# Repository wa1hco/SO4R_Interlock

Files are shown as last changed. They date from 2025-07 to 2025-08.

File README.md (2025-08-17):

# SO4R_Interlock V2
The interlock manages up to 4 radios for a contesting scenario

Baseline capability for one SSB/CW radio plus 3 WSJTX radios.
Antenna separation is sufficient to allow reception when other radio is transmitting
SSB/CW radio has an amplifier and rotatable antenna

Each of three WSJTx instances have radio and antenna (generally fixed).  Amplifier is shared among radios
WSJTX feeds N1MM, Gridtracker or other program that display a combined list of stations needed.
Operator clicks on a station in the list and that WSJTX begins the contact.
SSB/CW operator can continue to operate, which interrupts WSJTX transmission.

Each of 4 radio have a priority with SSB/CW being highest
SSB/CW operation can continue while WSJTX is making contacts while staying within the ARRL VHF contest rules

When a higher priority tranmitter needs to interrupt a lower priority tranmission, 
the interlock gates the PTT line to the lower priority radio.  This keeps the radio's
built in sequencer operating to protect the amplifier, preamp, and relays.  
The interlock also controls the RF relays to disconnect the lower priority transmitter 
and connect the highest priority transmitter

Radio Interface
* PTT, output open collector, low true, 60V, 300 mA
* KEY, input, open collector, low true, 5 to 15 V
* CAT, bidirectional, open collector, ttl levels, serial communication
* Spare, direct connection to MCU I/O pin

Relay interface
* Relay output are drive high from nominal 12V source
  * uses BTS5200-4 driver chip for fault protection and diagnositc capability
* 12V is sourced from a rig interface for from coaxial type M connector
* each output drives DPDT transfer relay and one port of 4:1 selector on both amp input and output

USB serial interface
* Implemented with FTDI FT230 usb serial chip
* TxD, RxD, for CAT
* RTS, output, for signaling Transmit
* CTS, input, available, interfaced to MCU, no function assigned
* USB EEPROM changed to make it easier to find the ports
  * Manufacturer is "FTDI WA1HCO"
  * Product is "FT230X SO4R Port {1-4}"

SSB/CW radio interface
* highest priority radio, Priority = 1
* USB serial TxD, RxD used for MCU programming
* USB serial RTS used for keying radio from N1MM
* KEY signal from Radio used to set priority and control relays

WSJTX radio interface
* Lower priority radios, Priority = 2, 3, or 4
* USB serial implements COM port used by WSJTX software
* Serial data TxD and RxD converted to CAT bidirectional open collector
* RTS signal used for Tx command to radio
* CTS signal routed to MCU but not assigned a function

WSJTX operation
* Operator uses ssb/cw radio for contacts and has highest priority for transmitting.
* 3 WSJTX instances listen on 3 radios in 3 directions.
* Each WSJTX sends it list of callsigns to N1MM or Gridtracker which displays list of needed stations.
* The operator clicks on a callsign in the list to start a WSJTX contact.
* WSJTX indicates need to transmit by asserting RTS on its serial interface

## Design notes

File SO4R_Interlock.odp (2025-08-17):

## SO4R Interlock System Engineering: Fred Lass, K2TR Design: Jeff Millar, WA1HCO

## Baseline SO4R Interlock System Diagram

FT8 PC

WSJT

Main rig interfaces

CAT, Tx Audio, Rx Audio

Transfer Relays

radio

Ant 4

FT8 PC

WSJT

RTS

CAT, Tx Audio, Rx Audio

PTT

radio

Ant 3

FT8 PC

WSJT

CAT, Tx Audio, Rx Audio

CAT, Tx Audio, Rx Audio, PTT, CW

SO4R

Interlock

Connectors USB-C, DC type M, RJ45

radio

Ant 2

SSB PC

N1MM

RTS

PTT

radio

Ant 1

WSJTX to rig interface

- CAT, Audio via rig USB

- Interlock USB used for RTS

Interlock determines priority

- Based on RTS or KEY inputs

- Highest priority gets PTT

SSB/CW rig sends KEY to Interlock

RTS flows to PTT if highest priority

RTS

USB

4

radio

4

4

PTT

4:1 Mux Relays

3

2

3

3

2

2

KEY

12V, if not from

rig interface

1

12V

1

1

RLY

Relay Control

radio 1, Mux 1

radio 2, Mux 2

radio 3, Mux 3

radio 4, Mux 4

Amp

Transfer relays connect

- Rig to antenna for Rx

- Rig to Amp to Antenna for Tx

Mux relays route priority rig thru amp

## SO4R Interlock Principles of Operation

- Interlock for four radios, ensures only one Tx at a time
  - Read RTS signals from WSJTX
  - Read KEY signal from SSB/CW Rig
  - Determine Priority from RTS and KEY inputs
  - Assert PTT to the highest priority WSJT rig if no SSB/CW key
  - Repeat every 20 to 50 usec
- SSB/CW radio has highest priority
  - Tx is controlled by VOX, Footswitch, CW key, not by Interlock
  - KEY from SSB/CW rig signal tells Interlock to block PTT to other rigs
- Interlock forwards WSJTX RTS signal to rig PTT

## SO4R Interlock Hardware Design

- FT230X USB serial interface
  - RTS to microcontroller
- Rig Interface, RJ45, 4 twisted pair of signal and ground
  - PTT output, open collector, 60V, 300 mA
  - KEY input, open collector, external pullup, protected to 15V
  - CAT in/out, open collector, 5V (growth option)
  - 12V, input from Rig, replaces ground on CAT pair
  - Spare (growth option)
- Relay Interface, RJ45, 4 twisted pair, relay and ground
  - Drive 12V to external relays,
  - Relay driver is BTS4200-4 with protection and diagnostics
  - Typically three Omron G2RL-1-E-12V with 80 mA draw per relay
- 12V, DC power for relays, need 240 mA
  - Used if Rig power not available
- AVR32DB48 microcontroller
  - Programmed using port 1 USB serial
  - Green LED for 5V power
  - White LEDs for serial traffic
- Electrical design
  - EMI filtering on all I/O
  - ESD protection on all inputs
  - 4 layer PCB
  - Three flooded ground planes
  - One flooded 5V plane
  - Interlock powered from any USB
  - Relays powered from any rig or 12V coaxial

## Interlock Schematic Diagram

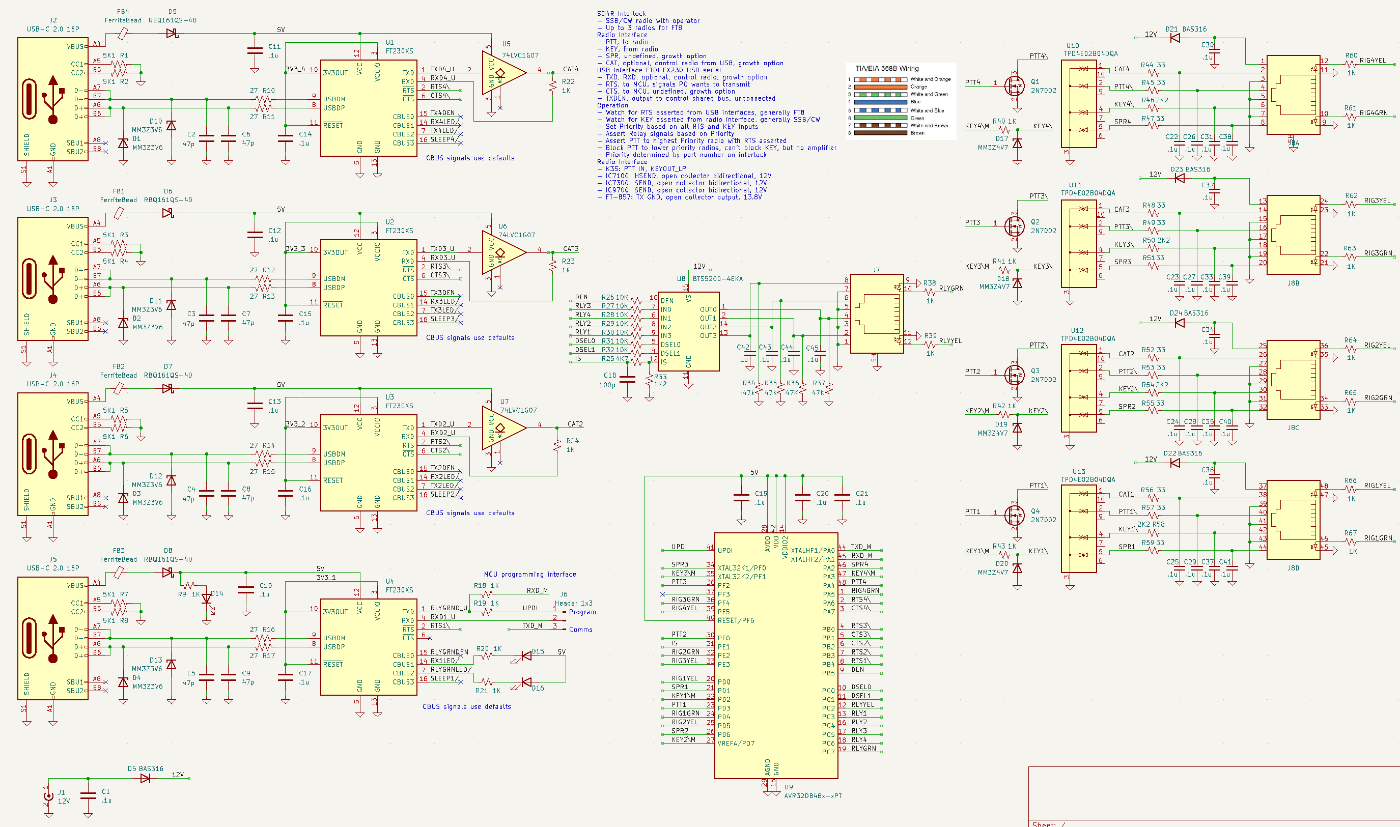
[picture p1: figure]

## SO4R Interlock Functional Design

- MicroController
  - Reads RTS and KEY inputs
  - Writes PTT, Relay, and indicator LED outputs
- Combinatorial logic with latency below 100 usec
- Relay protection relies on Rig Tx delay
- Rig timing assumptions
  - PTT asserted to rig causes KEY output from rig immediately (usec)
  - PTT asserted to RF output delayed by 15 msec or more
  - PTT release causes RF to stop in about 300 usec (filter delays)
  - PTT release causes KEY output to be released immediately (usec)
- Conclusion, no need for sequencing within Interlock

## Corner Cases

- Operator presses TX button on WSJT radio
  - LP radio _will_ go into transmit
  - Radio asserts KEY output
  - Interlock reads KEY and lights yellow LED on rig RJ45
  - Interlock does not assert relays, Tx power flows to antenna not amplifier
- If SSB/CW radio already transmitting
  - Relays set to SSB/CW radio uses amplifier
  - WSJT rig transfer relays remain in rig to antenna mode
  - LP Tx power flows to antenna
  - LP RJ45 shows Yellow LED on Interlock
- If HP radio starts Tx while LP Radio in Tx
  - Interlock sees KEY from HP radio
  - Interlock asserts relays for HP radio
  - LP radio RJ45 remains yellow
  - HP radio RJ45 shows green

## SO4R Interlock LEDs

- Each RJ45 connector has a green and a yellow LED
- Rig interface
  - Green LED means radio is transmitting
    - RTS asserted, highest priority, PTT asserted, Relays asserted
  - Yellow LED means radio wants to transmit but blocked
    - RTS asserted, not highest priority, PTT blocked by Interlock
    - KEY asserted because operator pressed Transmit on radio

## Interlock to Rig Interface Cables

- Make Cable
  - Use CAT 5/6 Ethernet cable
  - Cut in half to make two cables with RJ45
  - Expose 4 twisted pairs, strip ends
  - Solder on rig interface connectors
  - Strain Relief the junction
- Sample schematic on the right
  - Not based on experience with K3
  - Use KEY/, PTT/, and GND on DE15
  - Show ¼ inch phone jack and plug for PTT (optional)
  - Pick up 13.8V (optional)

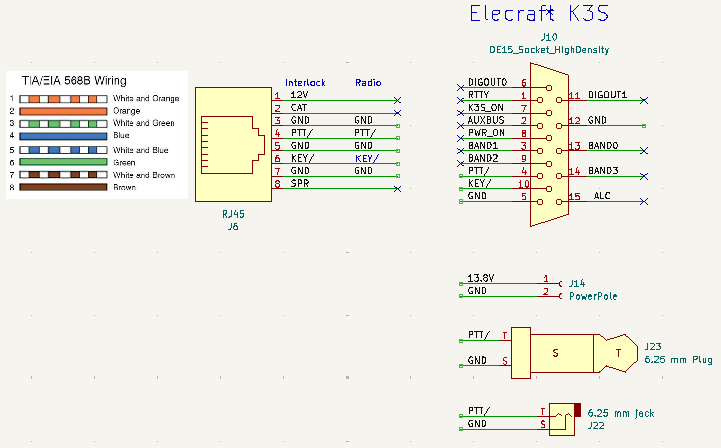
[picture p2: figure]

## WSJTX USB Interface from PC

- Separate USB interfaces
  - Linux WSJTX example shown
  - CAT Control USB
    - /dev/ttyUSB0
  - PTT Method USB set to RTS
    - /dev/ttyUSB1
- On Windows use separate COM ports for CAT and RTS

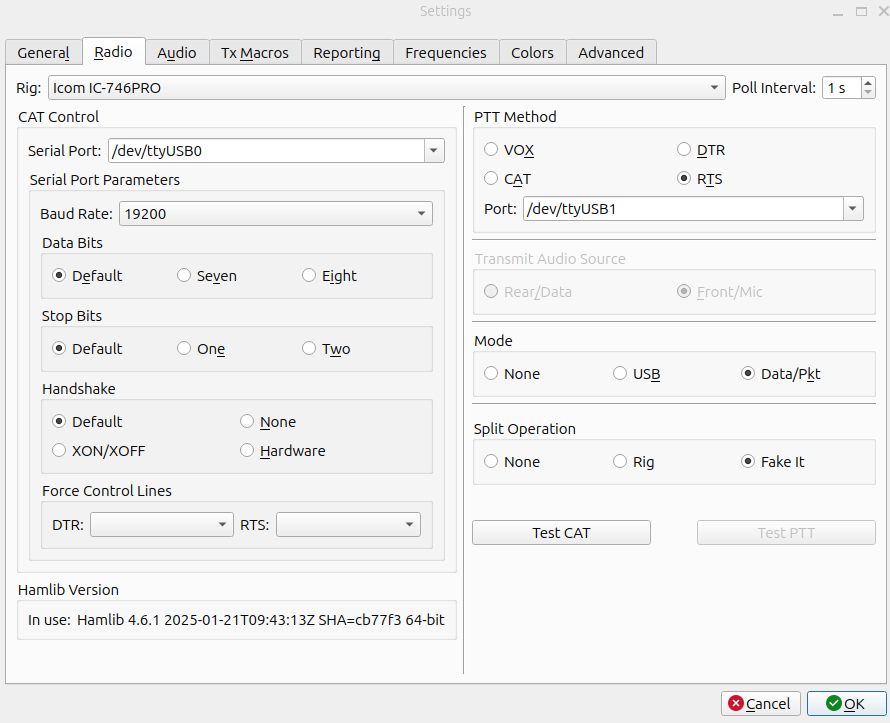
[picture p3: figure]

## Identifying Interlock USB ports

- USB interfaces on Interlock programmed to make it easier to identify on a PC
  - FT230X EEPROM has reprogramed ID _strings_
    - Manufacturer: “FTDI WA1HCO”
    - Product: “SO4R Port n” where n = {1, 2, 3, 4}
- CAUTION: USB has TWO sources of Manufacturer and Product info
  - Hex codes: Vendor ID (VID) = 0x0403, Product ID (PID) = 0x6015
  - Strings: Manufacturer = FTDI WA1HCO, Product = FT230X SO4R PORT 3
  - Device Manager translates VID and PID into default string for device
    - Doesn’t show the real strings within the device
  - On Windows, use USBView from Microsoft
    - Show programmed strings, used to find COM port number
    - https://learn.microsoft.com/en-us/windows-hardware/drivers/debugger/usbview

## SO4R Interlock Options and Growth

- Rig 2, 3, 4 RJ45 connector has growth options
  - Serial Rx and Tx converted to CAT open collector
  - CAT only for Rigs 2, 3, 4. Rig 1 Serial is for programming
  - Spare input/output
- Rig 1 RJ45 used for programming, not CAT
  - Serial port used for programming MCU
  - Serial port also available for user interface
- Relay driver, BTS4200-4 is connected to MCU
  - Fault detection, open, short, etc.
  - Measure relay currents

## Interlock Code (subject to change)

// Read all inputs, invert from low true to high true logic

bool RTS1 = !digitalRead(RTS1nPIN); // RTS from serial port asks for Tx

bool RTS2 = !digitalRead(RTS2nPIN);

bool RTS3 = !digitalRead(RTS3nPIN);

bool RTS4 = !digitalRead(RTS4nPIN);

bool KEY1 = !digitalRead(KEY1nPIN); // KEY from radio says Tx from RTS or manual

bool KEY2 = !digitalRead(KEY2nPIN);

bool KEY3 = !digitalRead(KEY3nPIN);

bool KEY4 = !digitalRead(KEY4nPIN);

// Compute Priority based on RTS and KEY inputs

// If no Tx requests, remains at 0 (Rx)

Priority = 0; // Rx mode

if (RTS4 or KEY4) Priority = 4; // WSJTX radio

if (RTS3 or KEY3) Priority = 3; // WSJTX radio

if (RTS2 or KEY2) Priority = 2; // WSJTX radio

if (RTS1 or KEY1) Priority = 1; // SSB/CW radio

// Output signals in order of timing criticality

// Assert Tx to relays

// Use priority set from RTS and KEY

// Relays asserted if either RTS or KEY input and priority

bool RLY1 = (Priority == 1);

bool RLY2 = (Priority == 2);

bool RLY3 = (Priority == 3);

bool RLY4 = (Priority == 4);

digitalWrite(RLY1PIN, RLY1);

digitalWrite(RLY2PIN, RLY2);

digitalWrite(RLY3PIN, RLY3);

digitalWrite(RLY4PIN, RLY4);

// Assert PTT to radios with RTS and corresponding to priority, all others stay Rx

// PTT asserted only on RTS and priority, do not use KEY

bool PTT1 = RTS1 and (Priority == 1);

bool PTT2 = RTS2 and (Priority == 2);

bool PTT3 = RTS3 and (Priority == 3);

bool PTT4 = RTS4 and (Priority == 4);

digitalWrite(PTT1PIN, PTT1);

digitalWrite(PTT2PIN, PTT2);

digitalWrite(PTT3PIN, PTT3);

digitalWrite(PTT4PIN, PTT4);

// Assert Rig RJ45 Green LED if rig is transmitting

digitalWrite(RIG1GRNPIN, RLY1);

digitalWrite(RIG2GRNPIN, RLY2);

digitalWrite(RIG3GRNPIN, RLY3);

digitalWrite(RIG4GRNPIN, RLY4);

// Assert Rig RJ45 Yellow LED if radio wants Tx but not highest priority

bool INH2 = (RTS2 or KEY2) and (Priority > 0) and (Priority < 2);

bool INH3 = (RTS3 or KEY3) and (Priority > 0) and (Priority < 3);

bool INH4 = (RTS4 or KEY4) and (Priority > 0) and (Priority < 4);

digitalWrite(RIG2YELPIN, INH2);

digitalWrite(RIG3YELPIN, INH3);

digitalWrite(RIG4YELPIN, INH4);

// Assert Relay RJ45 Green LED if any rig transmitting

// Assert Relay RJ45 Yellow LED if any rig inhibited

digitalWrite(RLYGRNPIN, RLY1 or RLY2 or RLY3 or RLY4);

digitalWrite(RLYYELPIN, INH2 or INH3 or INH4);

## Github Repository

- Project has three branches, main, V1.1, and V2
  - Use V2 as of 8/25
  - https://github.com/wa1hco/SO4R_Interlock/tree/V2
- Within a branch
  - Hardware, Kicad schematics, etc
    - SO4R_Interlock
    - Radio_Interface_Cables
    - Transfer_G2RL
  - Software
    - vscode, PlatformIO, Arduino Framework
  - Readme.md

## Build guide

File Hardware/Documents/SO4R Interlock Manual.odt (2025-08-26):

SO4R Interlock

Logic Board

MCU code

Transfer Relay

Amplifier Multiplexer

Concept by Fred Lass K2TR

Implementation by Jeff Millar WA1HCO

Version 1

Interlock Overview

Interlock Schematic

Interlock PCB layout

# SO4R_Interlock

The interlock manages up to 4 radios for the ARRL June and September VHF contest. The design follows the rules for those contests. Other contests have different rules.

## Overall Design

- Four radios and 4 antennas on 6 meters
- One SSB/CW radio plus three WSJTX radios.
- Antenna separation is sufficient to allow reception when another radio is transmitting
- One amplifier shared among four radios
- SSB/CW radio has rotatable antenna
- Each WSJTX radio has an antenna (generally fixed, optionally rotatable)
- WSJTX feeds N1MM, Gridtracker or other program that display a combined list of stations needed.
- SSB/CW has highest priority and will stop transmission of WSJTX if necessary
- Operator can click on a station in the list and that WSJTX begins the contact.
- SSB/CW operator can continue to operate, which interrupts WSJTX transmission.

## Overall Operation

### Running Scenario

SSB/CW operator calling CQ on SSB/CW

Operator monitors a combined list of stations heard presented by N1MM, GridTracker, etc

Operator clicks on a station in the list and corresponding WSJTX enables TX

Operator continues CQ on SSB/CW while WSJTX is making contacts

PTT to WSJTX radio is interrupted when

while staying within the ARRL VHF contest rules

When a higher priority tranmitter needs to interrupt a lower priority tranmission,

the interlock gates the PTT line to the lower priority radio. This keeps the radio's

built in sequencer operating to protect the amplifier, preamp, and relays.

The interlock also controls the RF relays to disconnect the lower priority transmitter

and connect the highest priority transmitter

Radio Interface

* PTT, output open collector, low true, 60V, 300 mA

* KEY, input, open collector, low true, 5 to 15 V

* CAT, bidirectional, open collector, ttl levels, serial communication

* Spare, direct connection to MCU I/O pin

Relay interface

* 4 Relay control output with 60V 300 mA capability

* each output drives DPDT transfer relay and one port of 4:1 selector on both amp input and output

USB serial interface

* Implemented with FTDI FT230 usb serial chip

* TxD, RxD for CAT

* RTS, output, for signaling Transmit

* CTS, input, available, interfaced to MCU, no function assigned

SSB/CW radio interface

* highest priority radio, Priority = 1

* USB serial TxD, RxD used for MCU programming

* USB serial RTS used for keying radio from N1MM

* KEY signal from Radio used to set priority and control relays

WSJTX radio interface

* Lower priority radios, Priority = 2, 3, or 4

* USB serial implements COM port used by WSJTX software

* Serial data TxD and RxD converted to CAT bidirectional open collector

* RTS signal used for Tx command to radio

* CTS signal routed to MCU but not assigned a function

WSJTX operation

* Operator uses ssb/cw radio for contacts and has highest priority for transmitting.

* 3 WSJTX instances listen on 3 radios in 3 directions.

* Each WSJTX sends it list of callsigns to N1MM or Gridtracker which displays list of needed stations.

* The operator clicks on a callsign in the list to start a WSJTX contact.

* WSJTX indicates need to transmit by asserting RTS on its serial interface

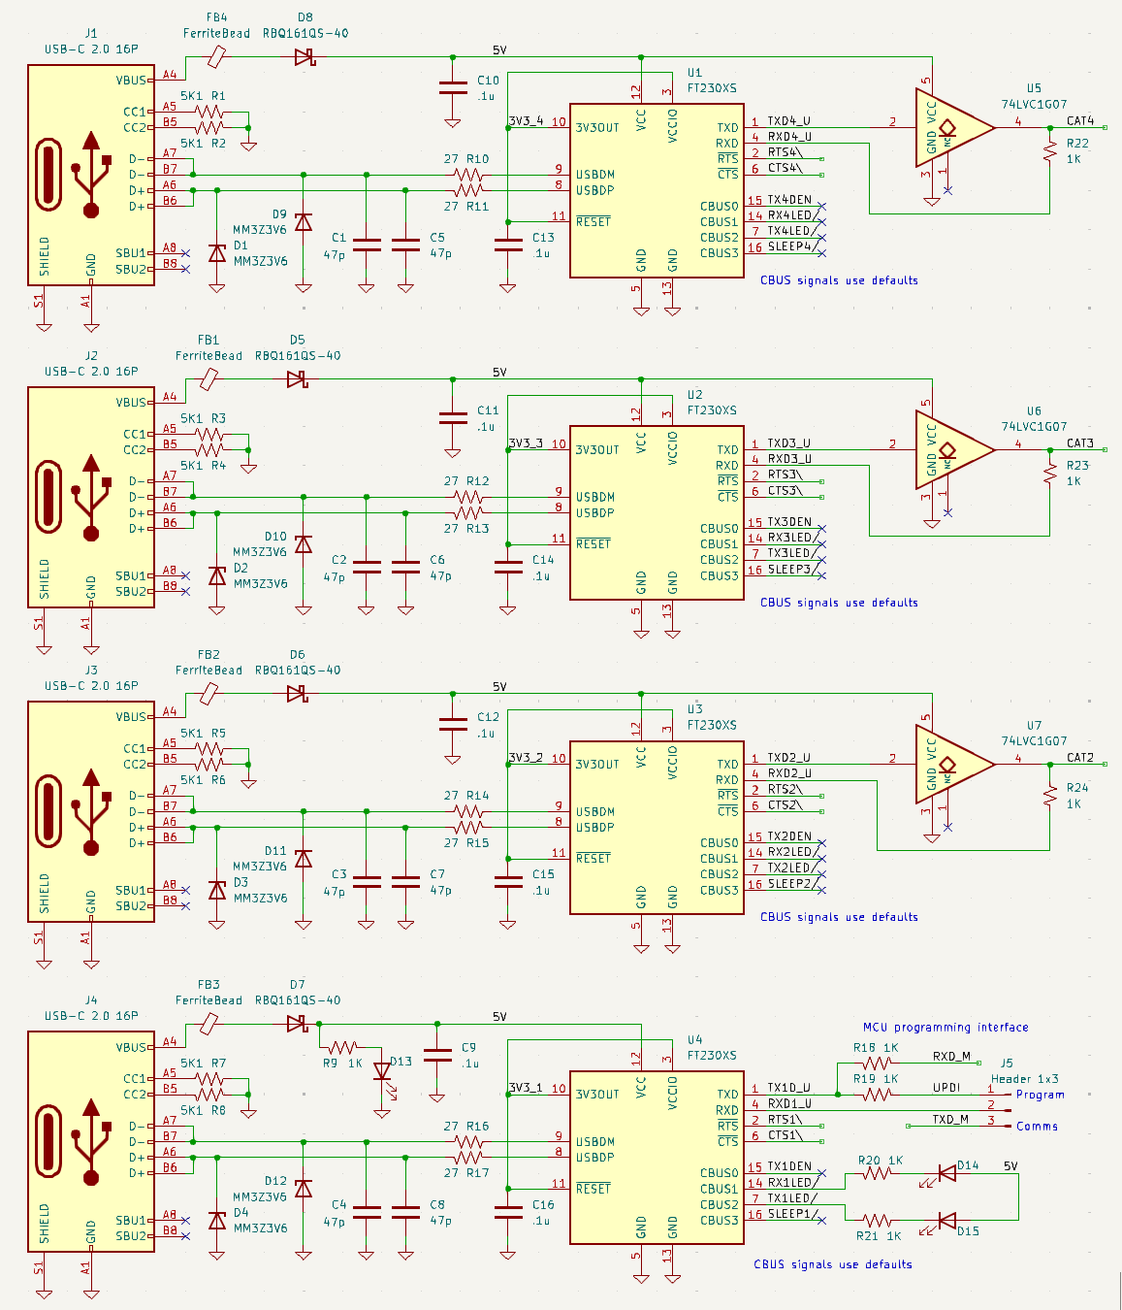
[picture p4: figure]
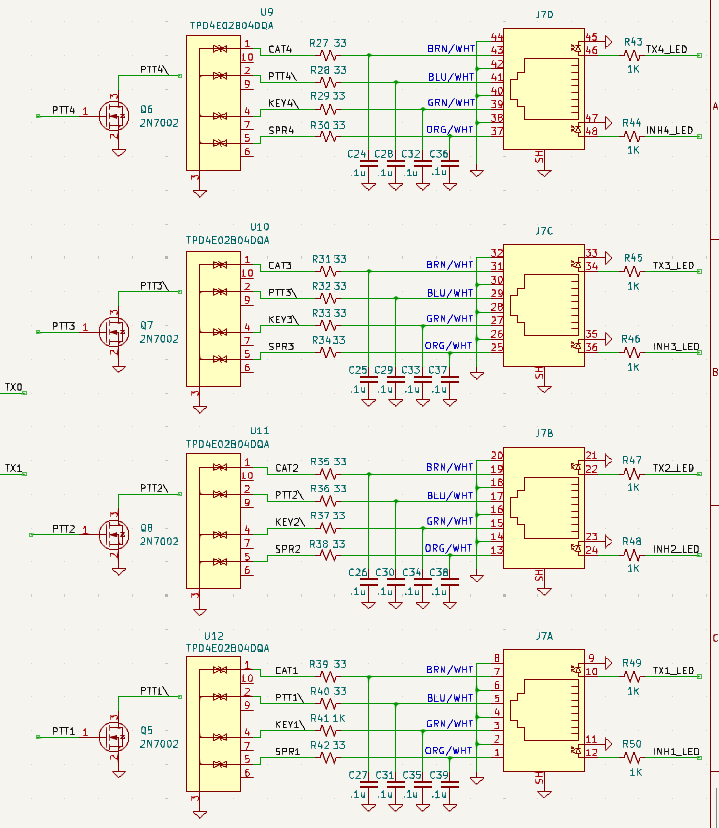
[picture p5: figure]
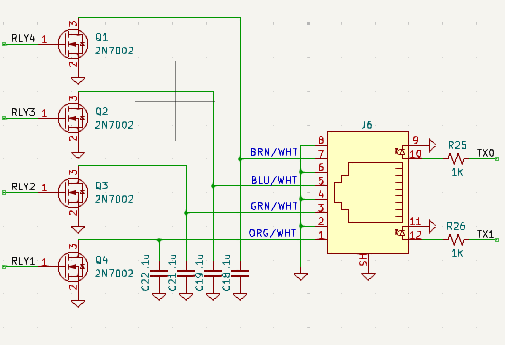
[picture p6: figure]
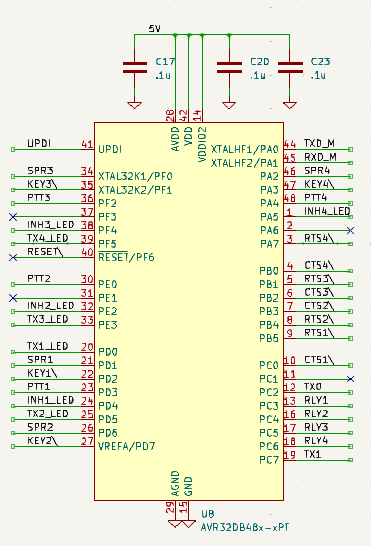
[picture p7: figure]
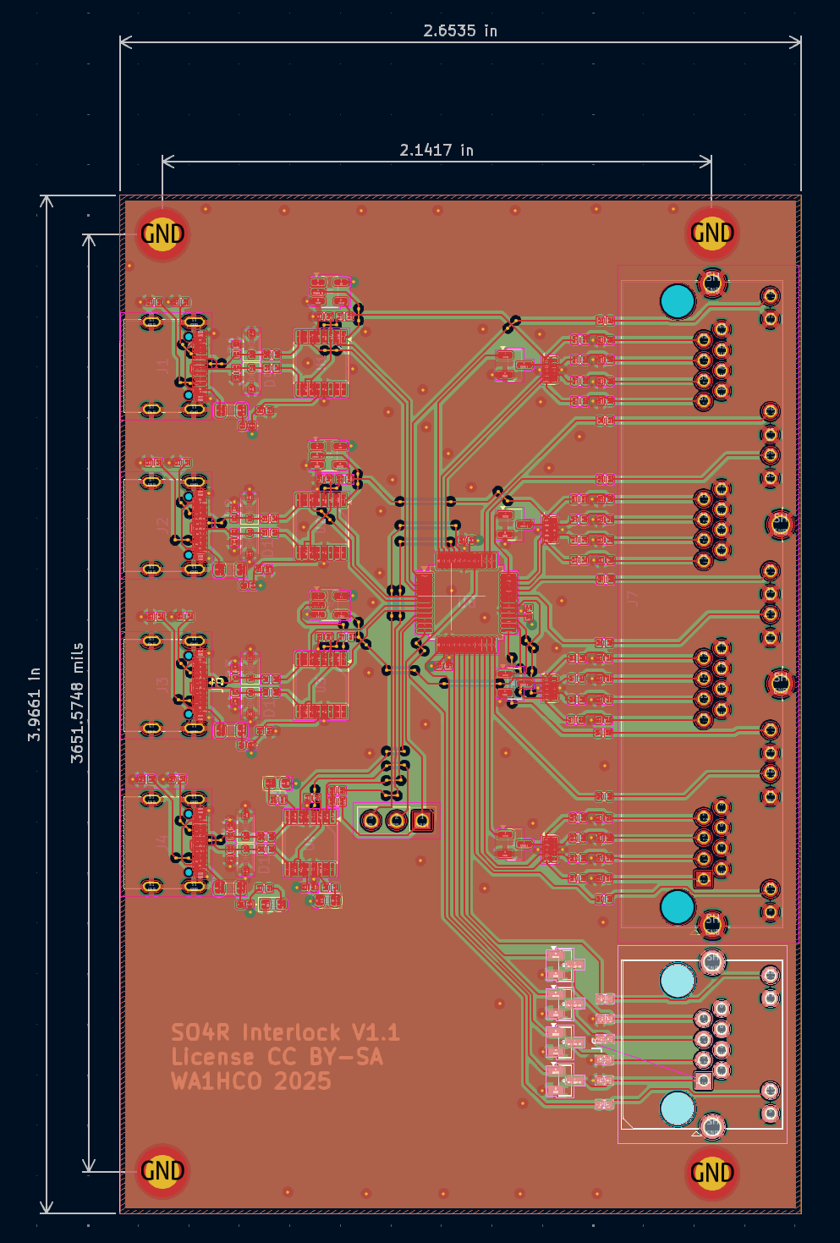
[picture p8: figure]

# Radio Connectors

## Icom IC-9700

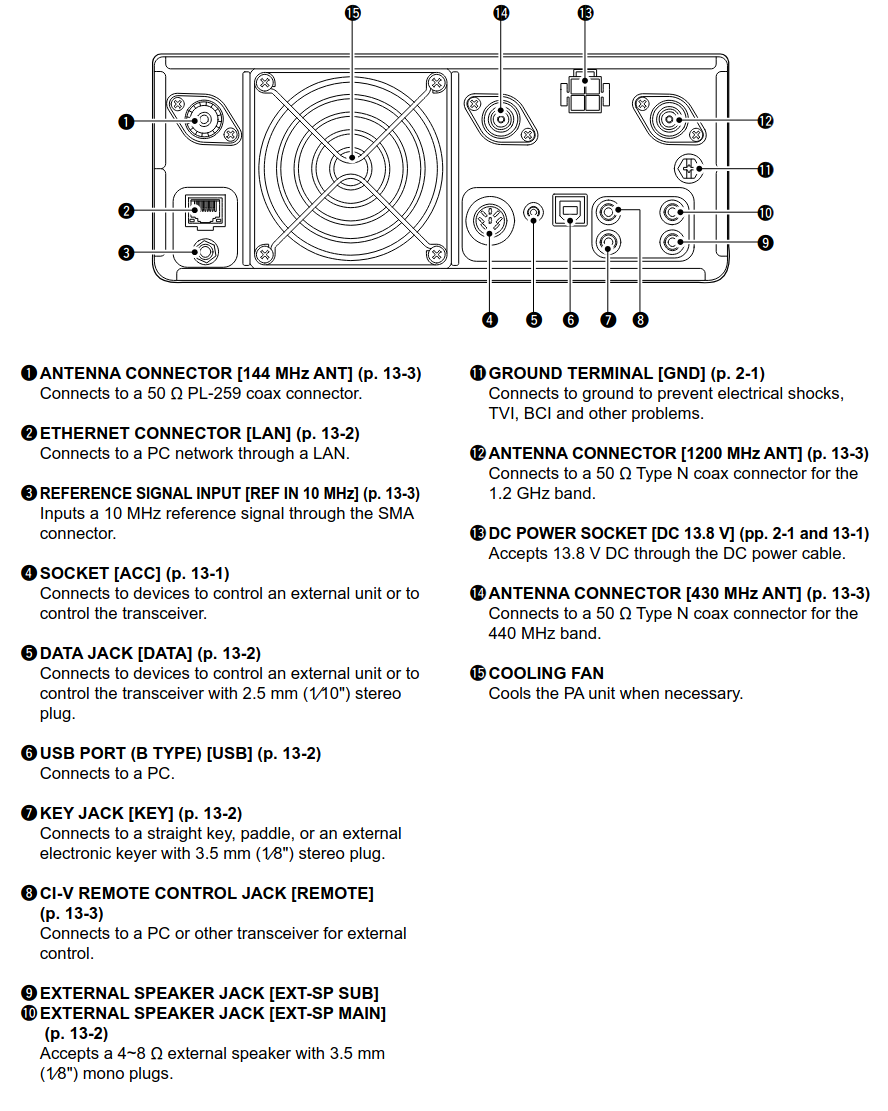
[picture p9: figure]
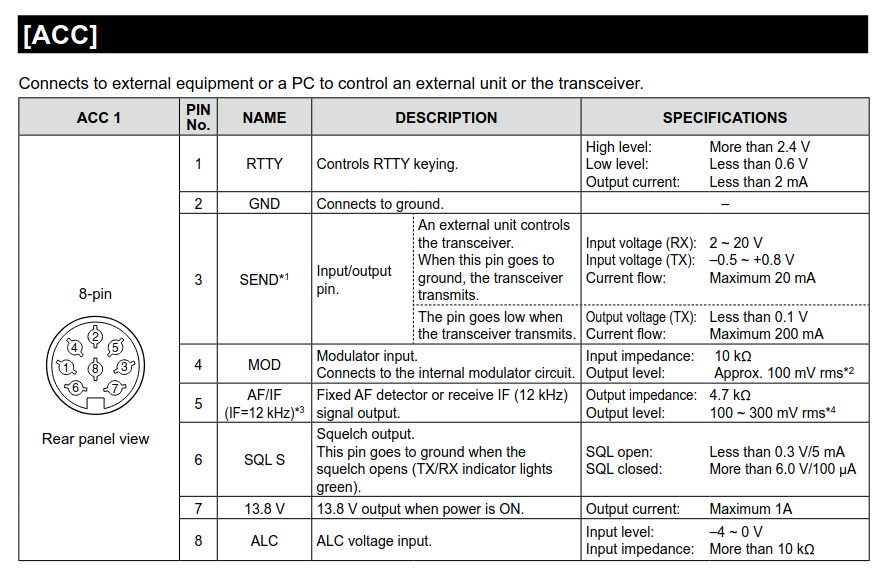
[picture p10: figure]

Note: Send is bidirectional can be used like PTT and asserted when radio goes to Tx from VOX, Tx button, etc. This mean that manually asserting Tx cannot be blocked. But if it is not highest priority, then the transfer relay remains in rig connected to antenna state and amplifier not deployed.

## Icom IC-9100

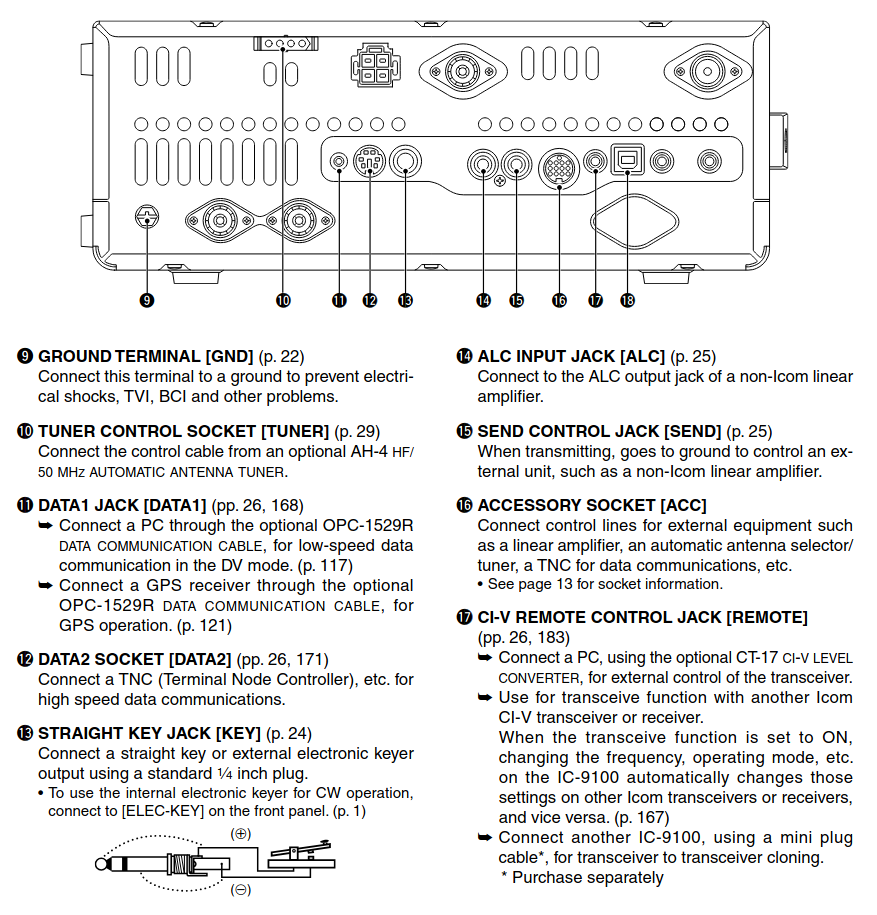
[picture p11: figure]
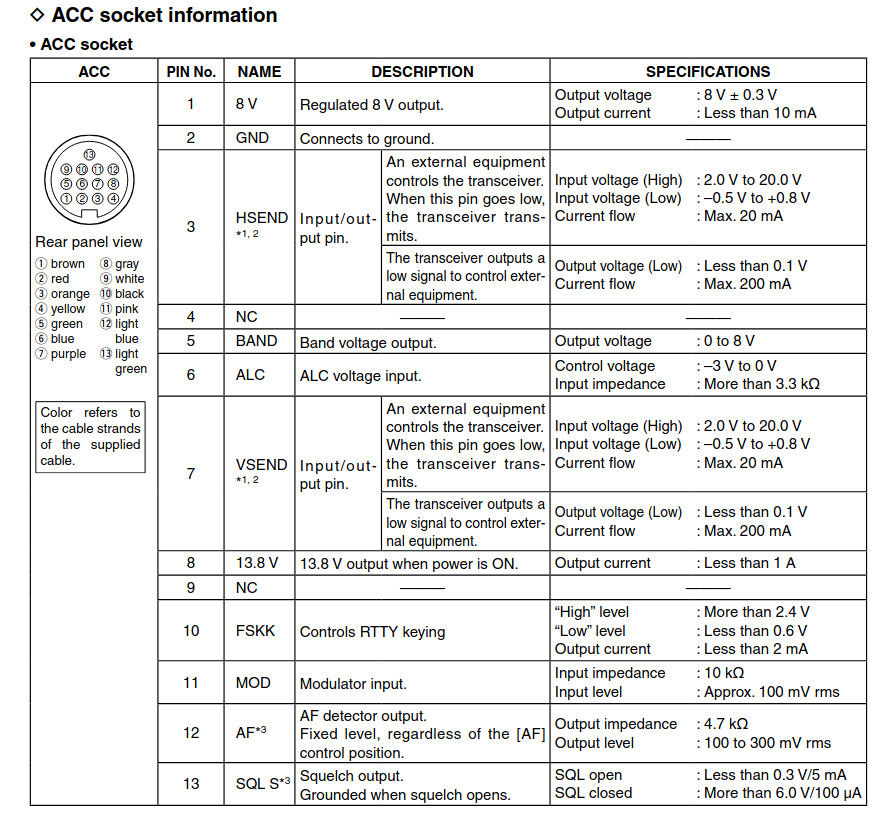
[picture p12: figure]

## Icom IC-746Pro

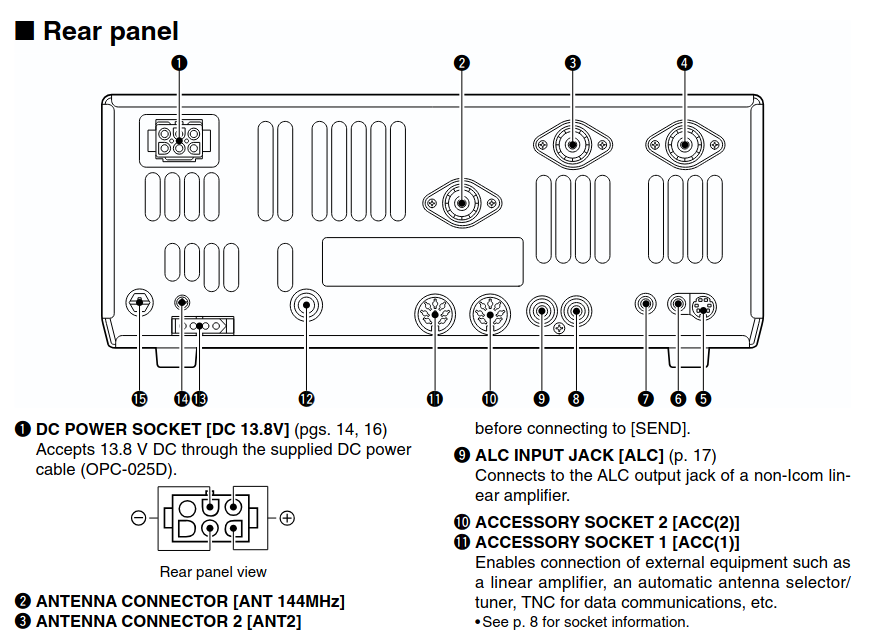
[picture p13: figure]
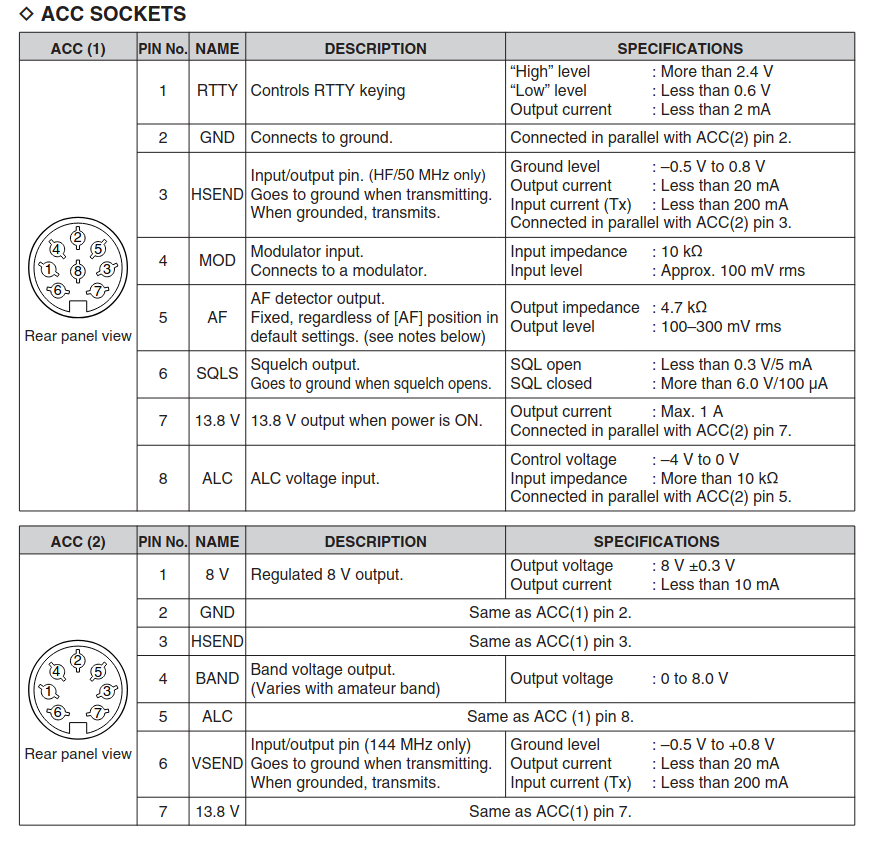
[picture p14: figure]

## Elecraft K3

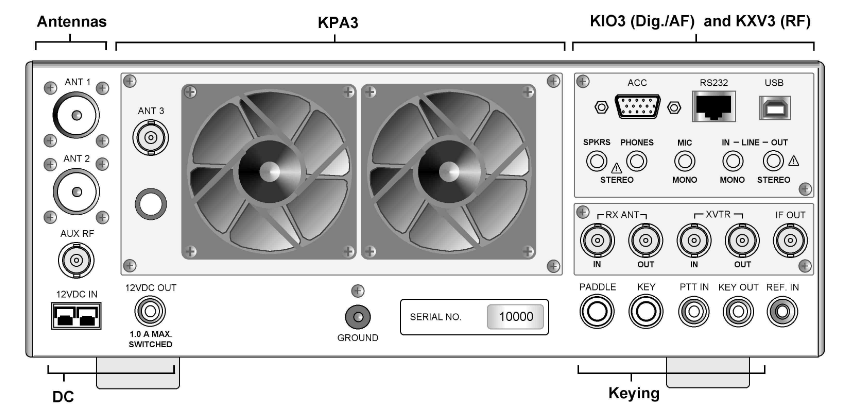
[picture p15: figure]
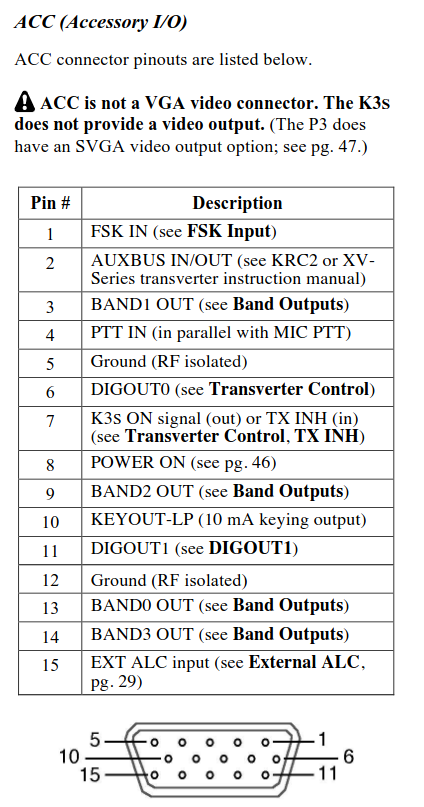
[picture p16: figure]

## Elecraft K4

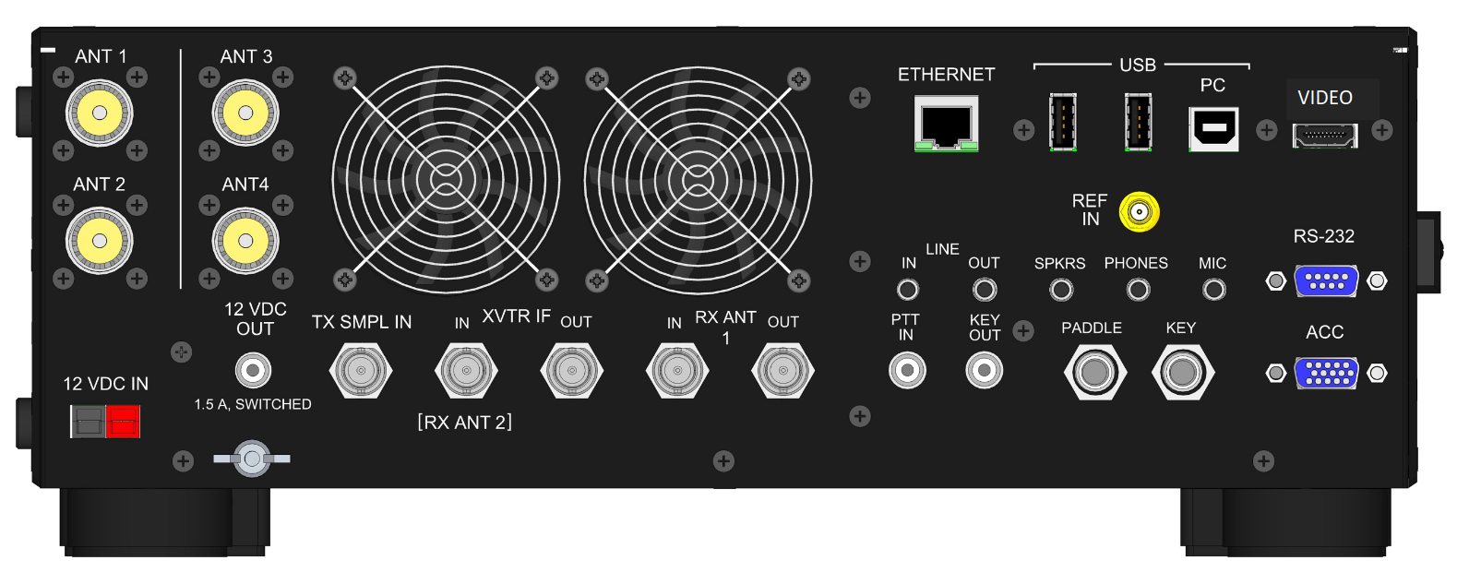
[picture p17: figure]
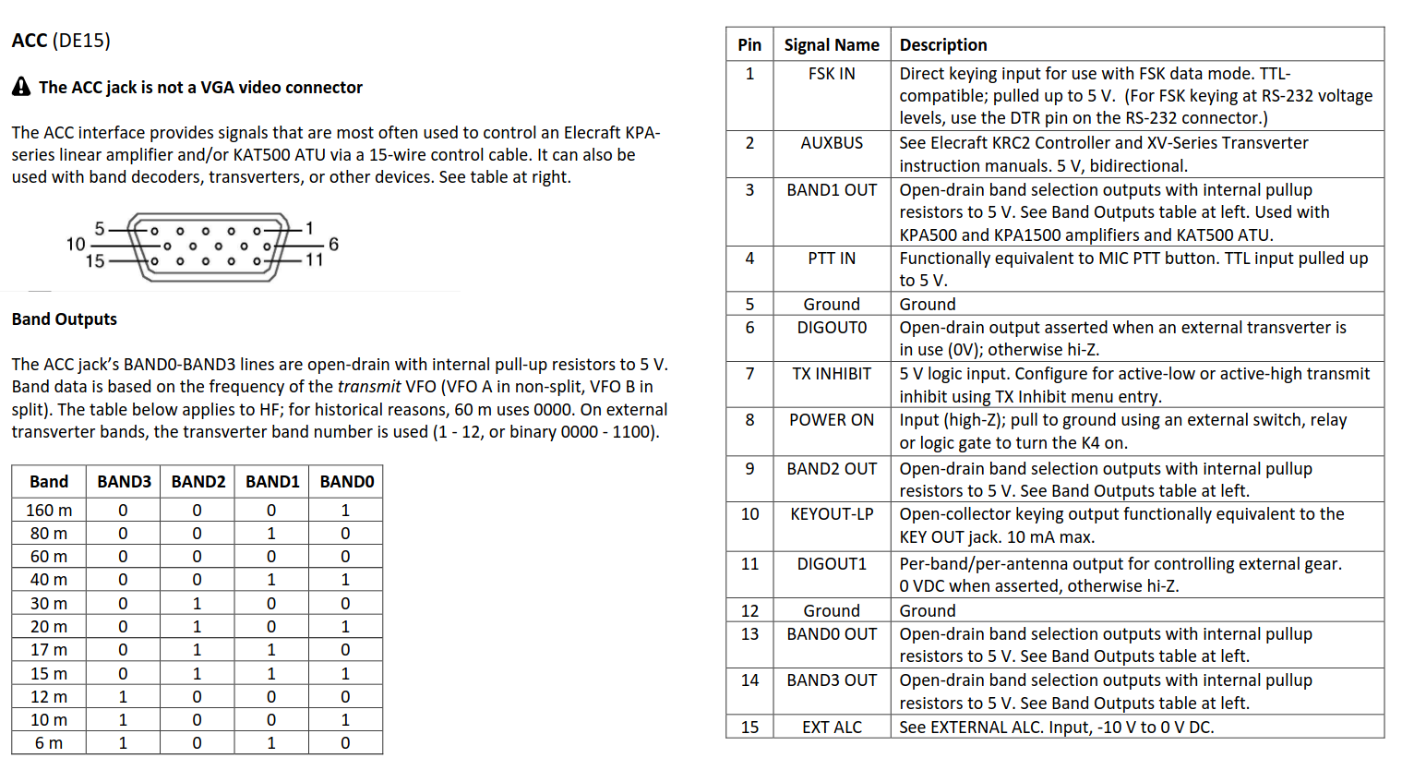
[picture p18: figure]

Yaesu FT-857

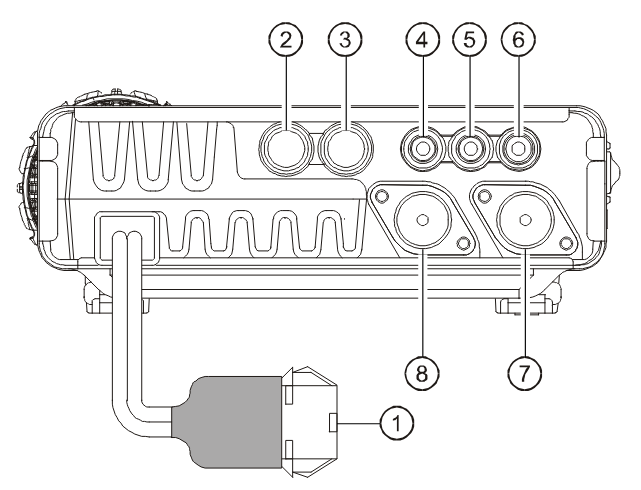
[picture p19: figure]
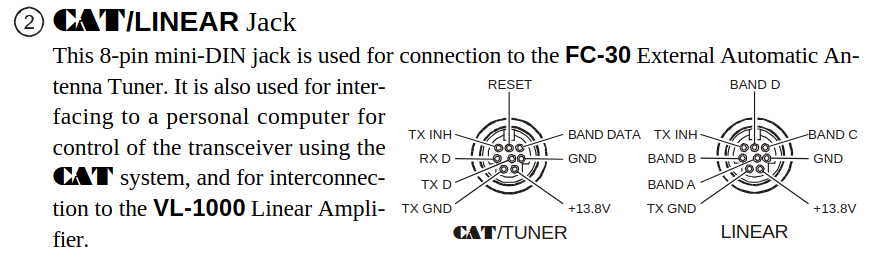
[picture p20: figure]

Note: Tx Gnd indicates radio in Tx mode, open collector , 50V 400 mA

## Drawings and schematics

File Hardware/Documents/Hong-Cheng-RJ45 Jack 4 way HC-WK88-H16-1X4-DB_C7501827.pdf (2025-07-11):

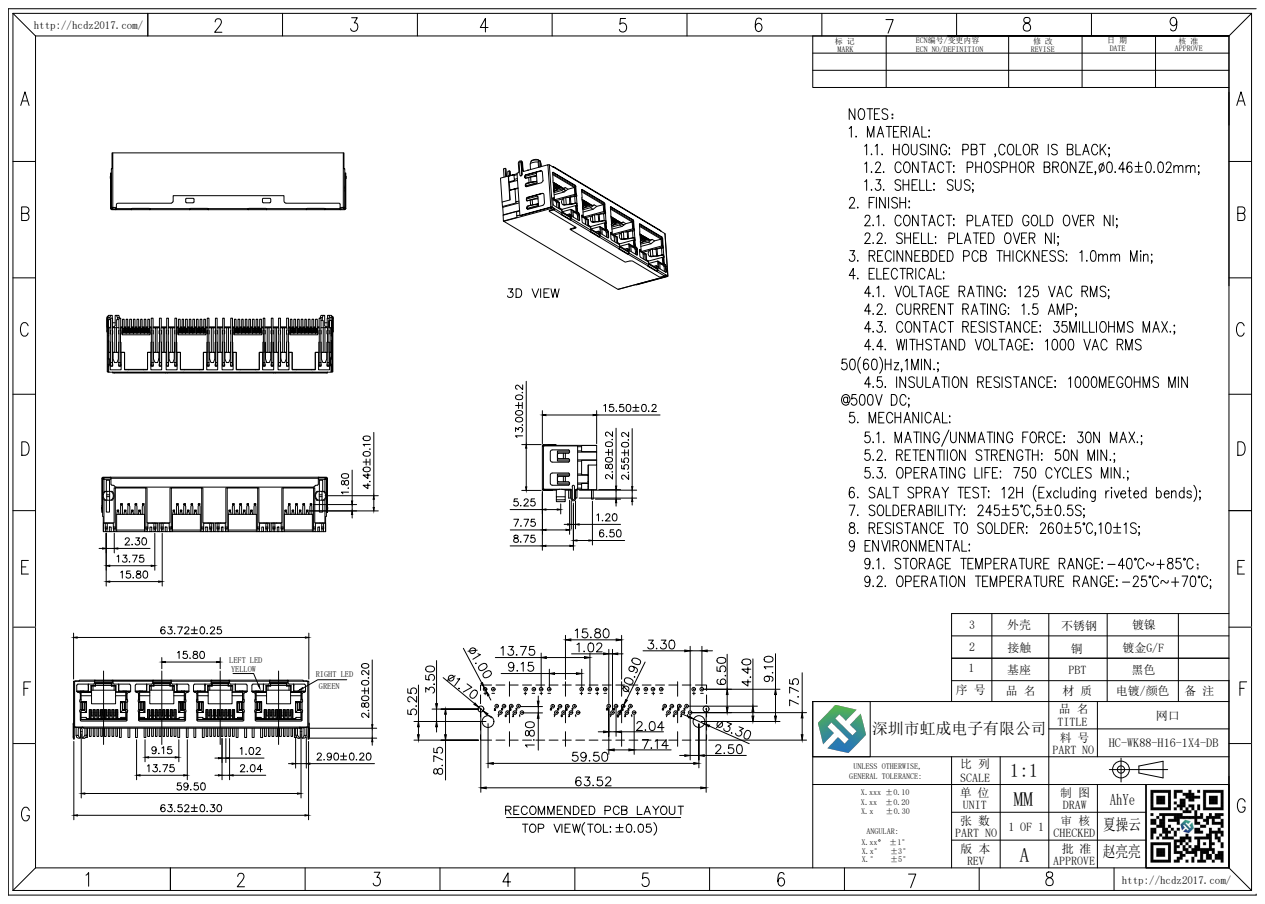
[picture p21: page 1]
UNLESS OTHERWISE, GENERAL TOLERANCE: X.xxx ±0.10 X.xx ±0.20 X.x; ±5° ANGULAR:：; ； DATE 日 期 REVISE 修 改 ECN NO/DEFINITION ECN编号/变更内容 MARK 标 记; APPROVE 核 准 品 名 TITLE PART NO 料 号 比 列 SCALE REV 版 本; DRAW 制 图 CHECKED 审 核 APPROVE 批 准 1:1 1 OF 1; 夏操云 AhYe http://hcdz2017.com/; http://hcdz2017.com/ UNIT 单 位; MM 深圳市虹成电子有限公司; 张 数 PART NO; PBT; 镀金G/F 3; 不锈钢; 镀镍 LEFT LED YELLOW; RIGHT LED GREEN

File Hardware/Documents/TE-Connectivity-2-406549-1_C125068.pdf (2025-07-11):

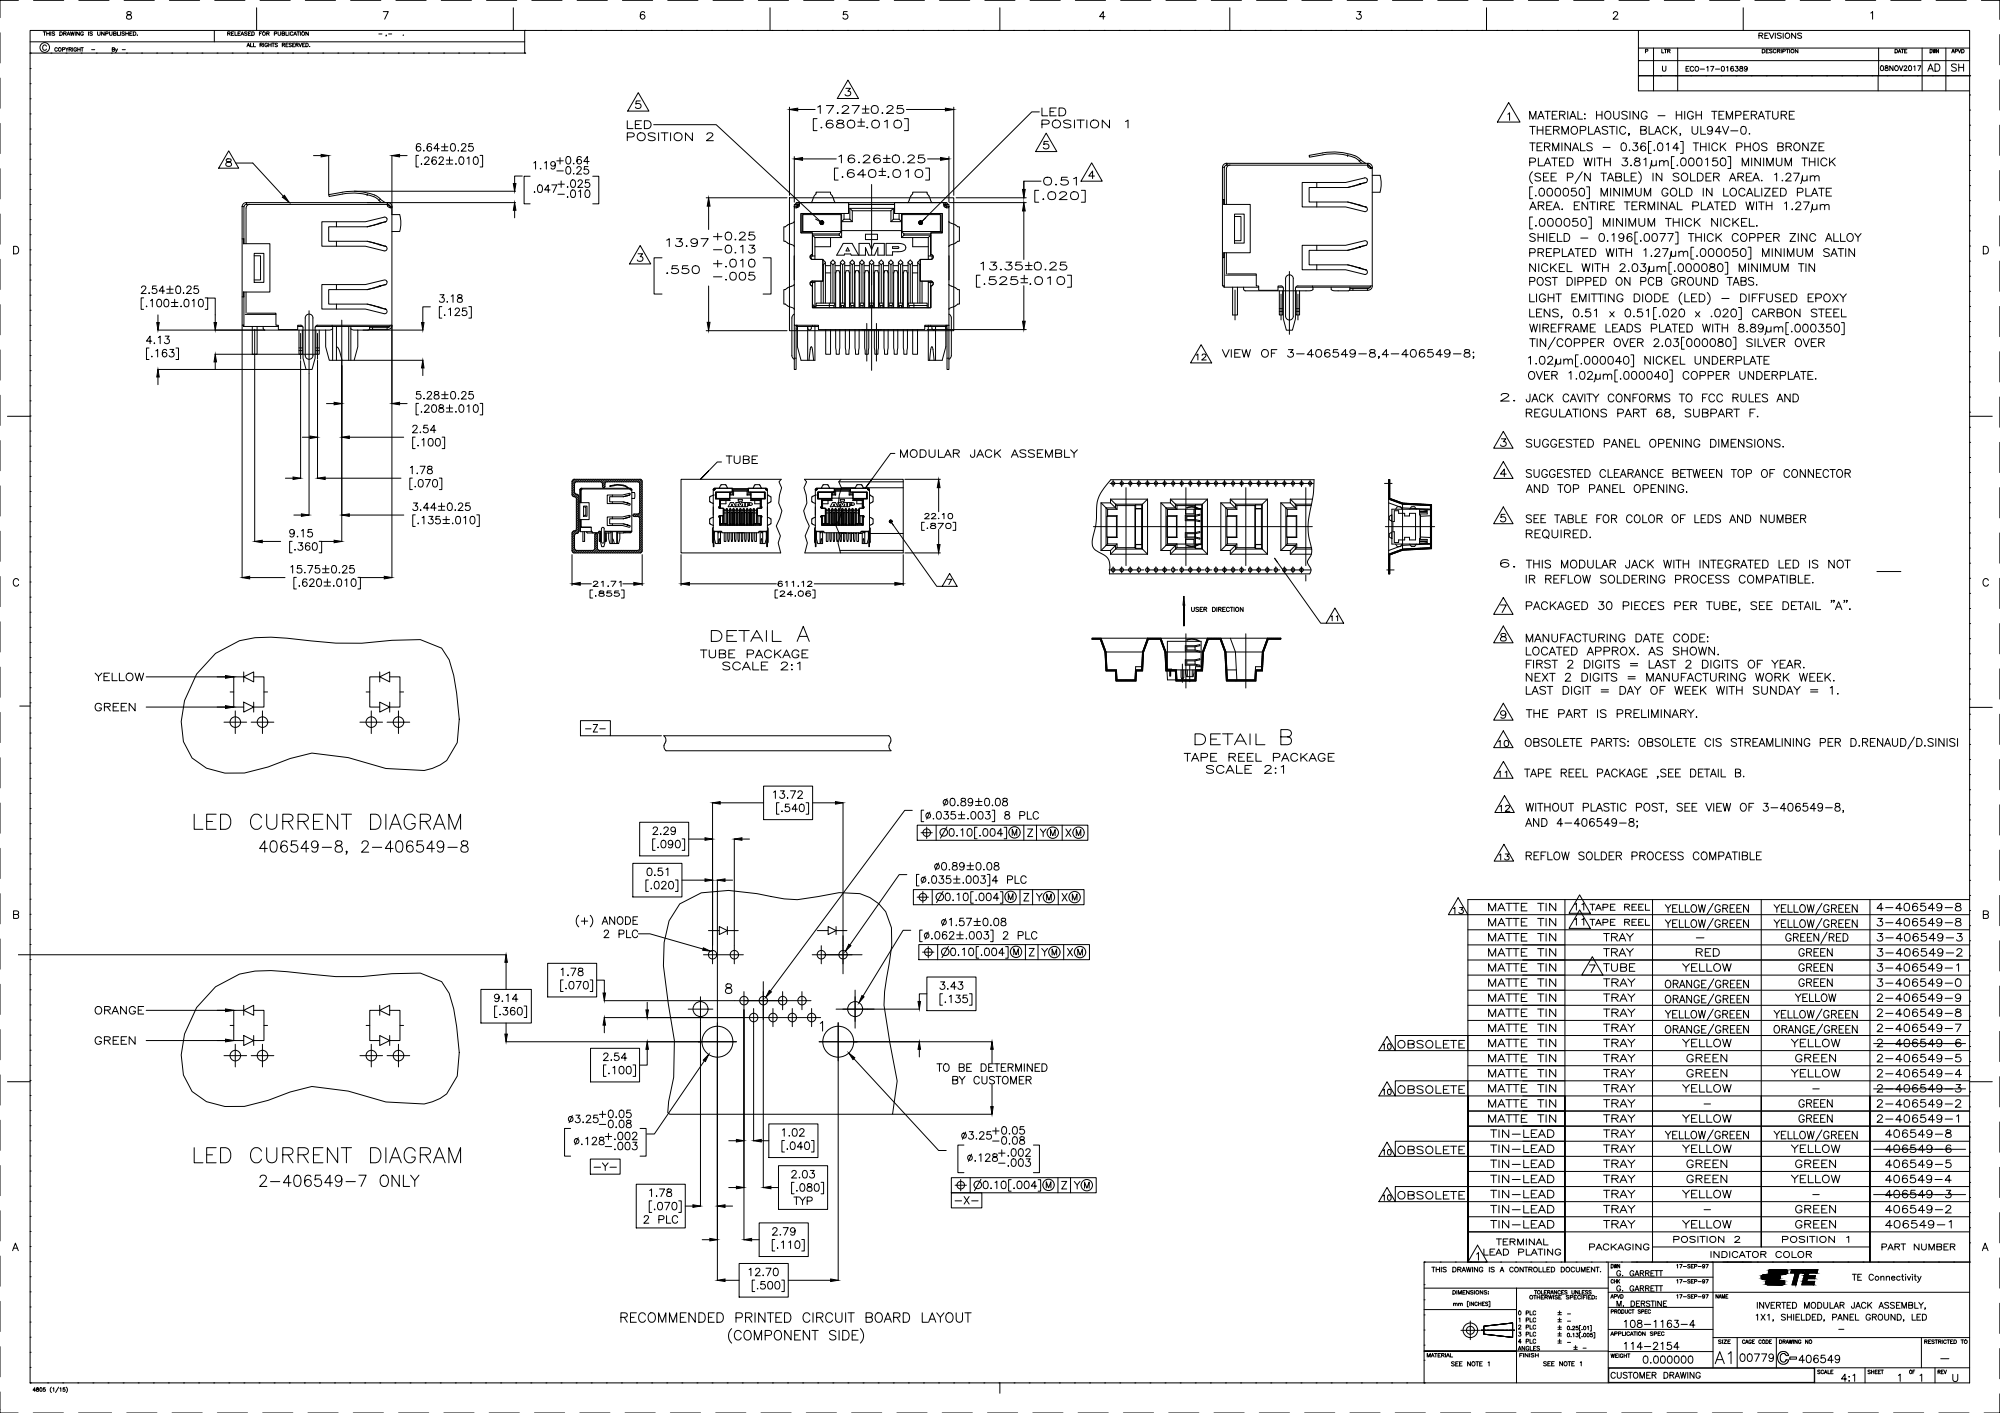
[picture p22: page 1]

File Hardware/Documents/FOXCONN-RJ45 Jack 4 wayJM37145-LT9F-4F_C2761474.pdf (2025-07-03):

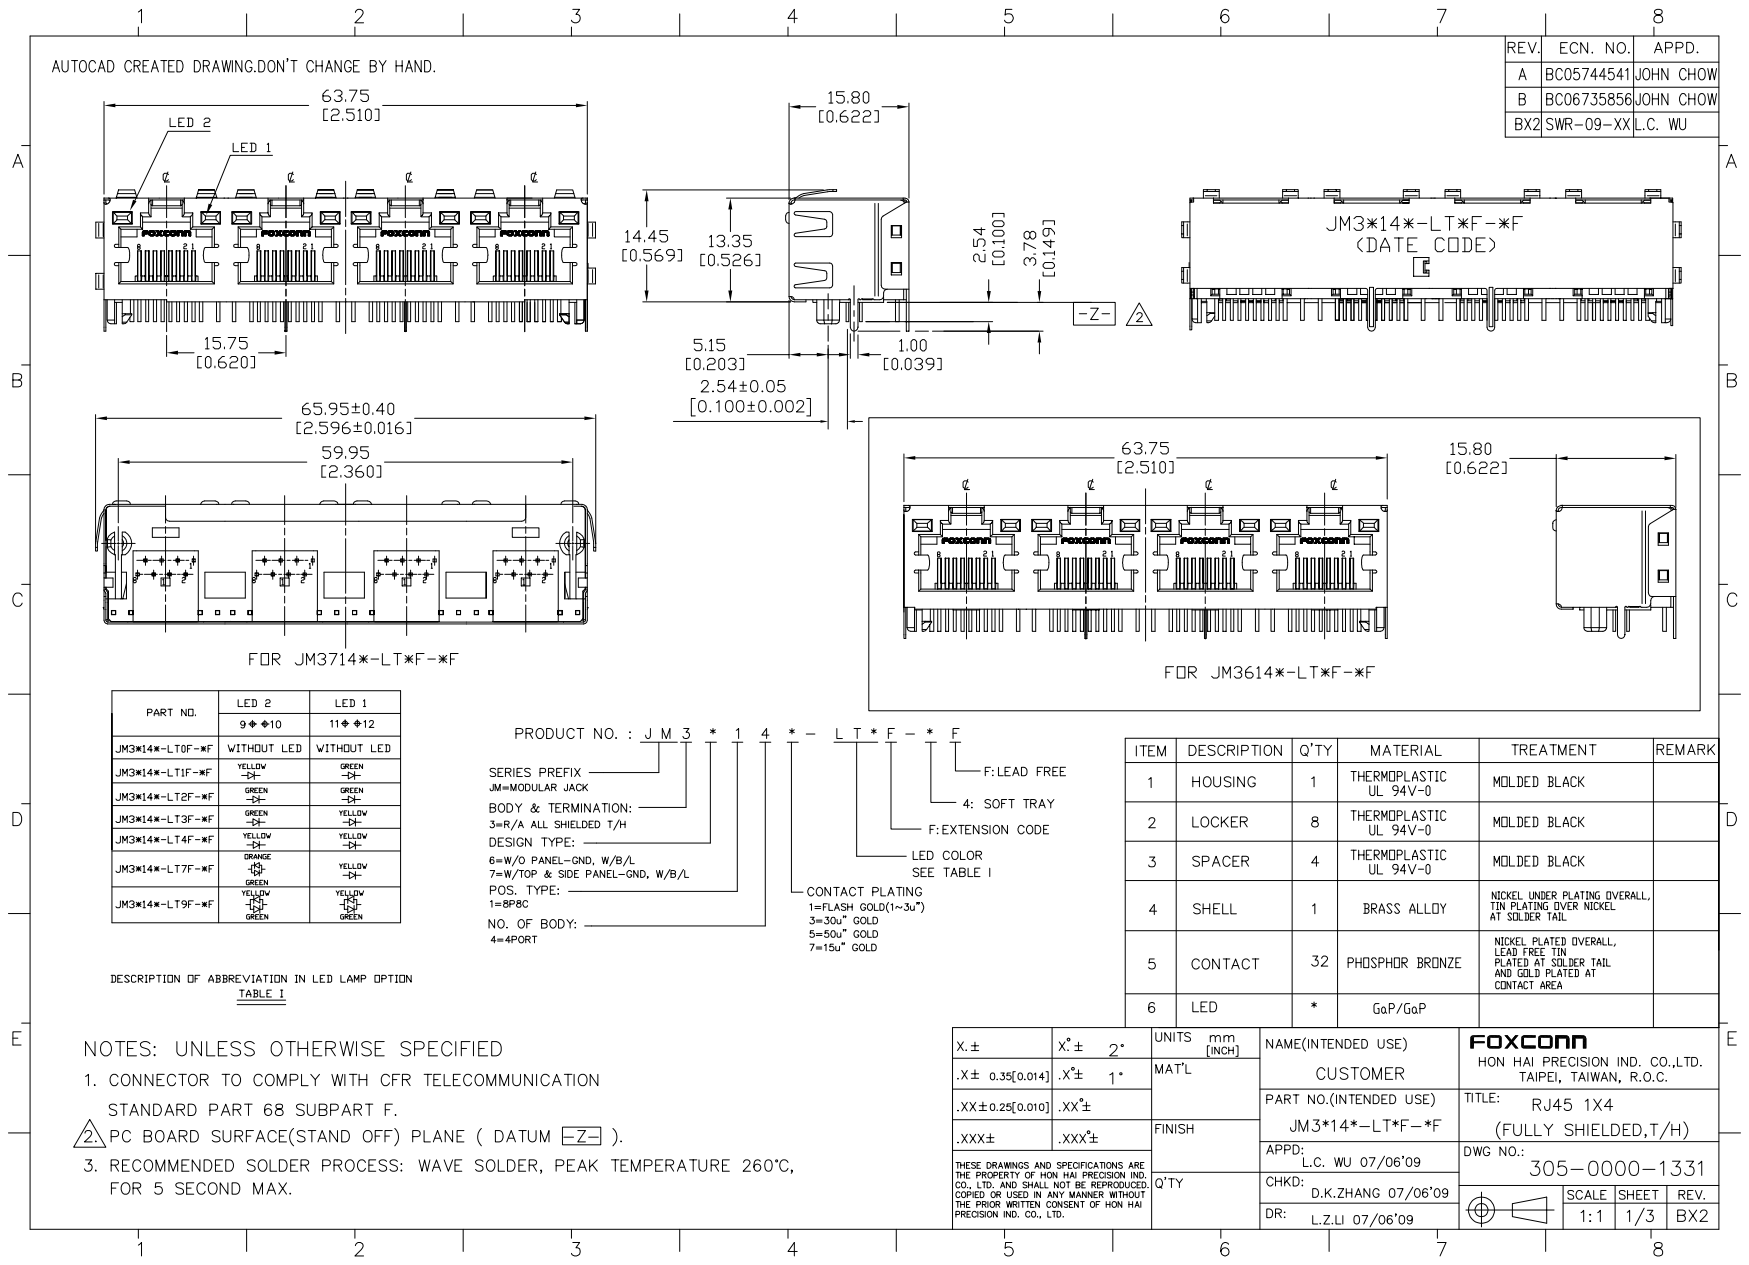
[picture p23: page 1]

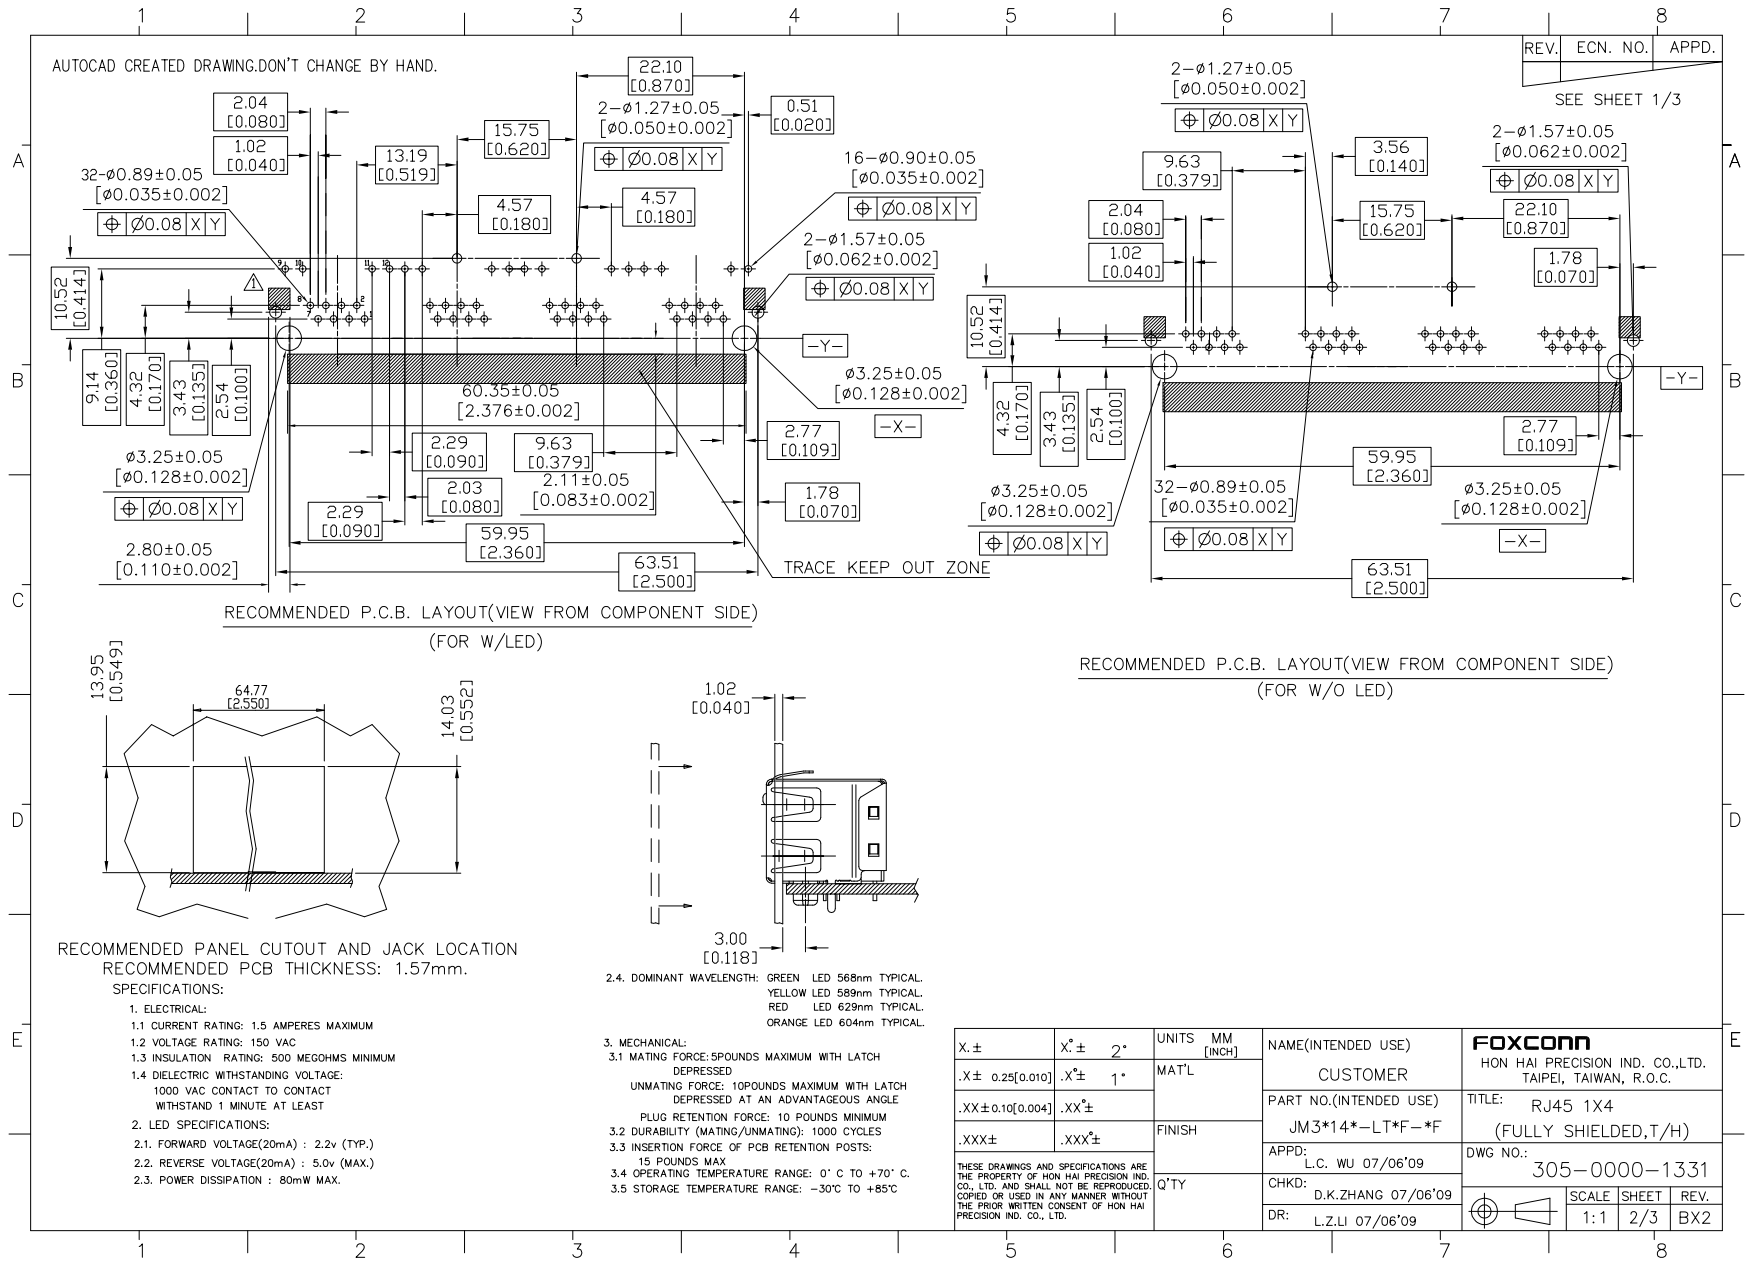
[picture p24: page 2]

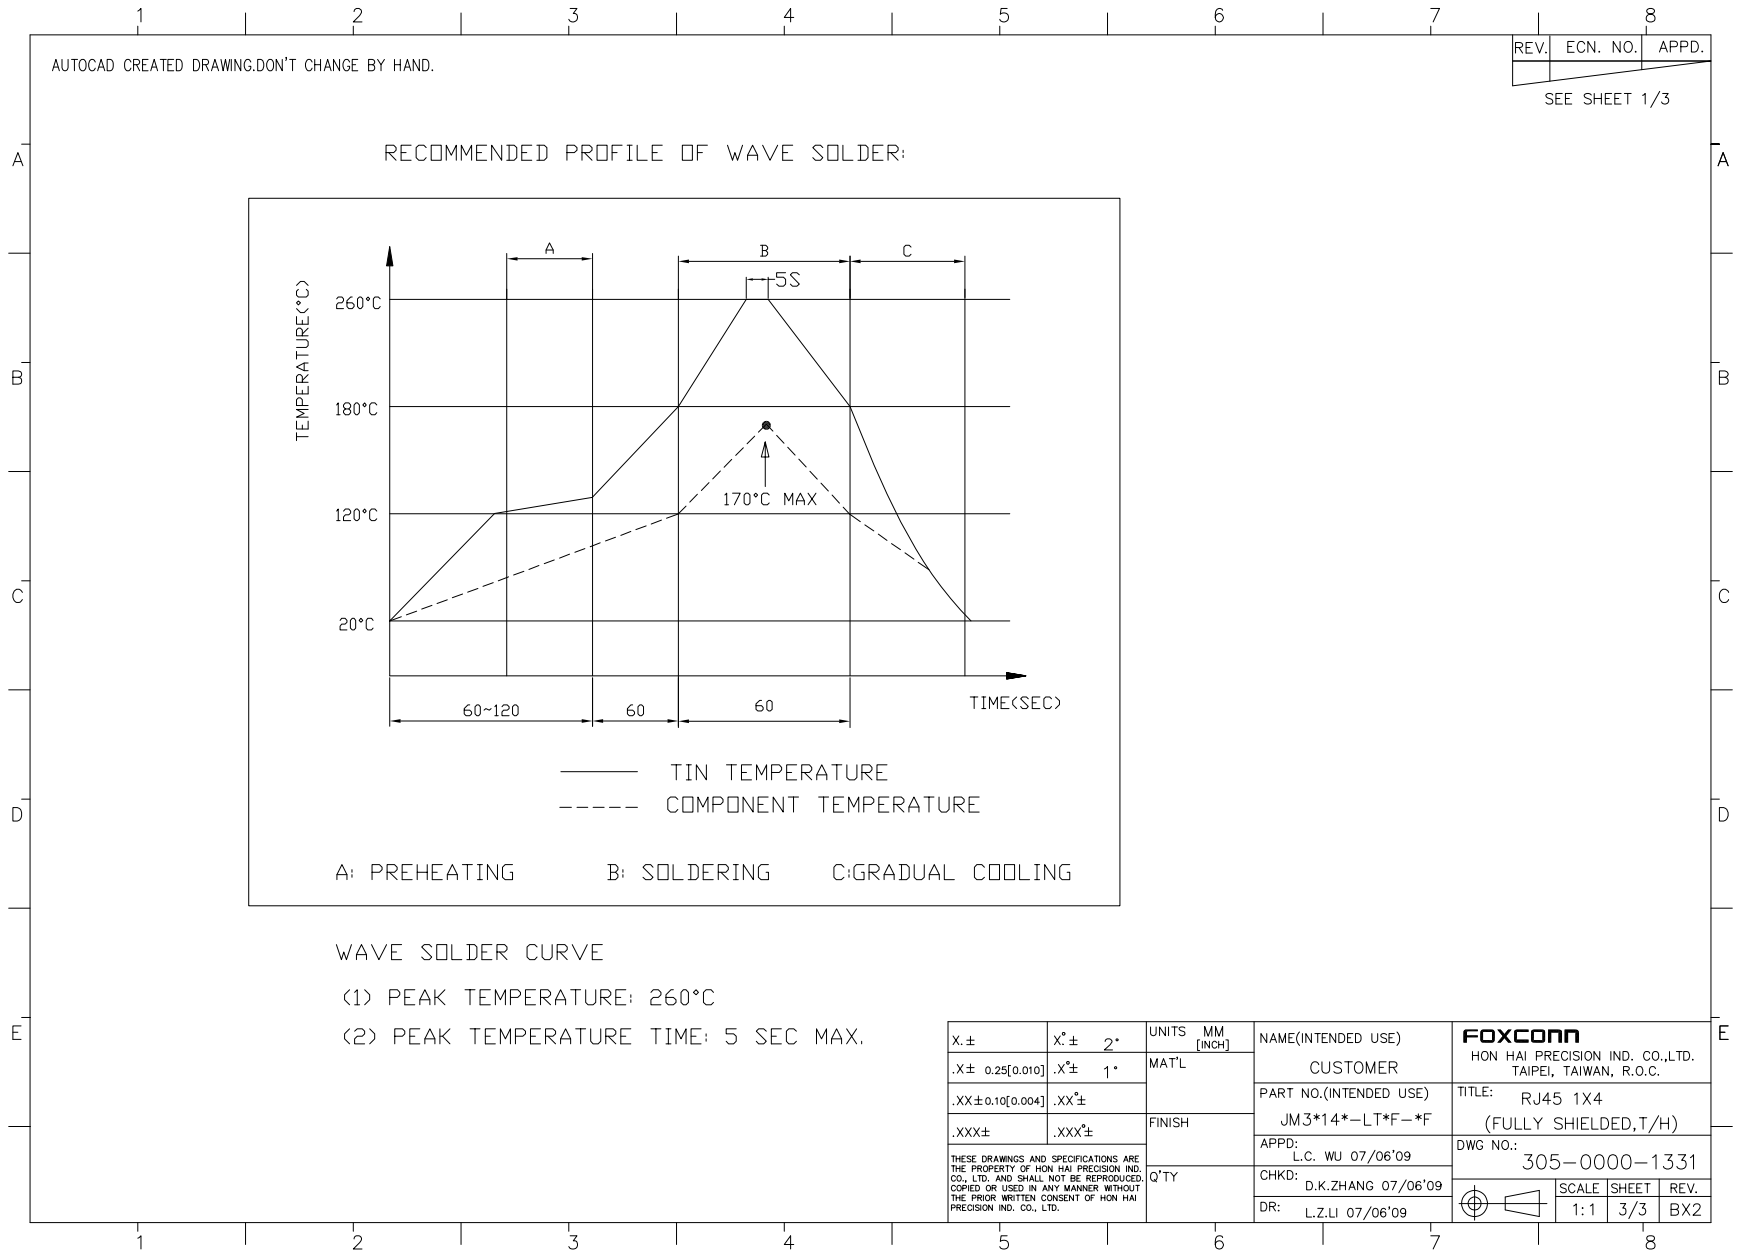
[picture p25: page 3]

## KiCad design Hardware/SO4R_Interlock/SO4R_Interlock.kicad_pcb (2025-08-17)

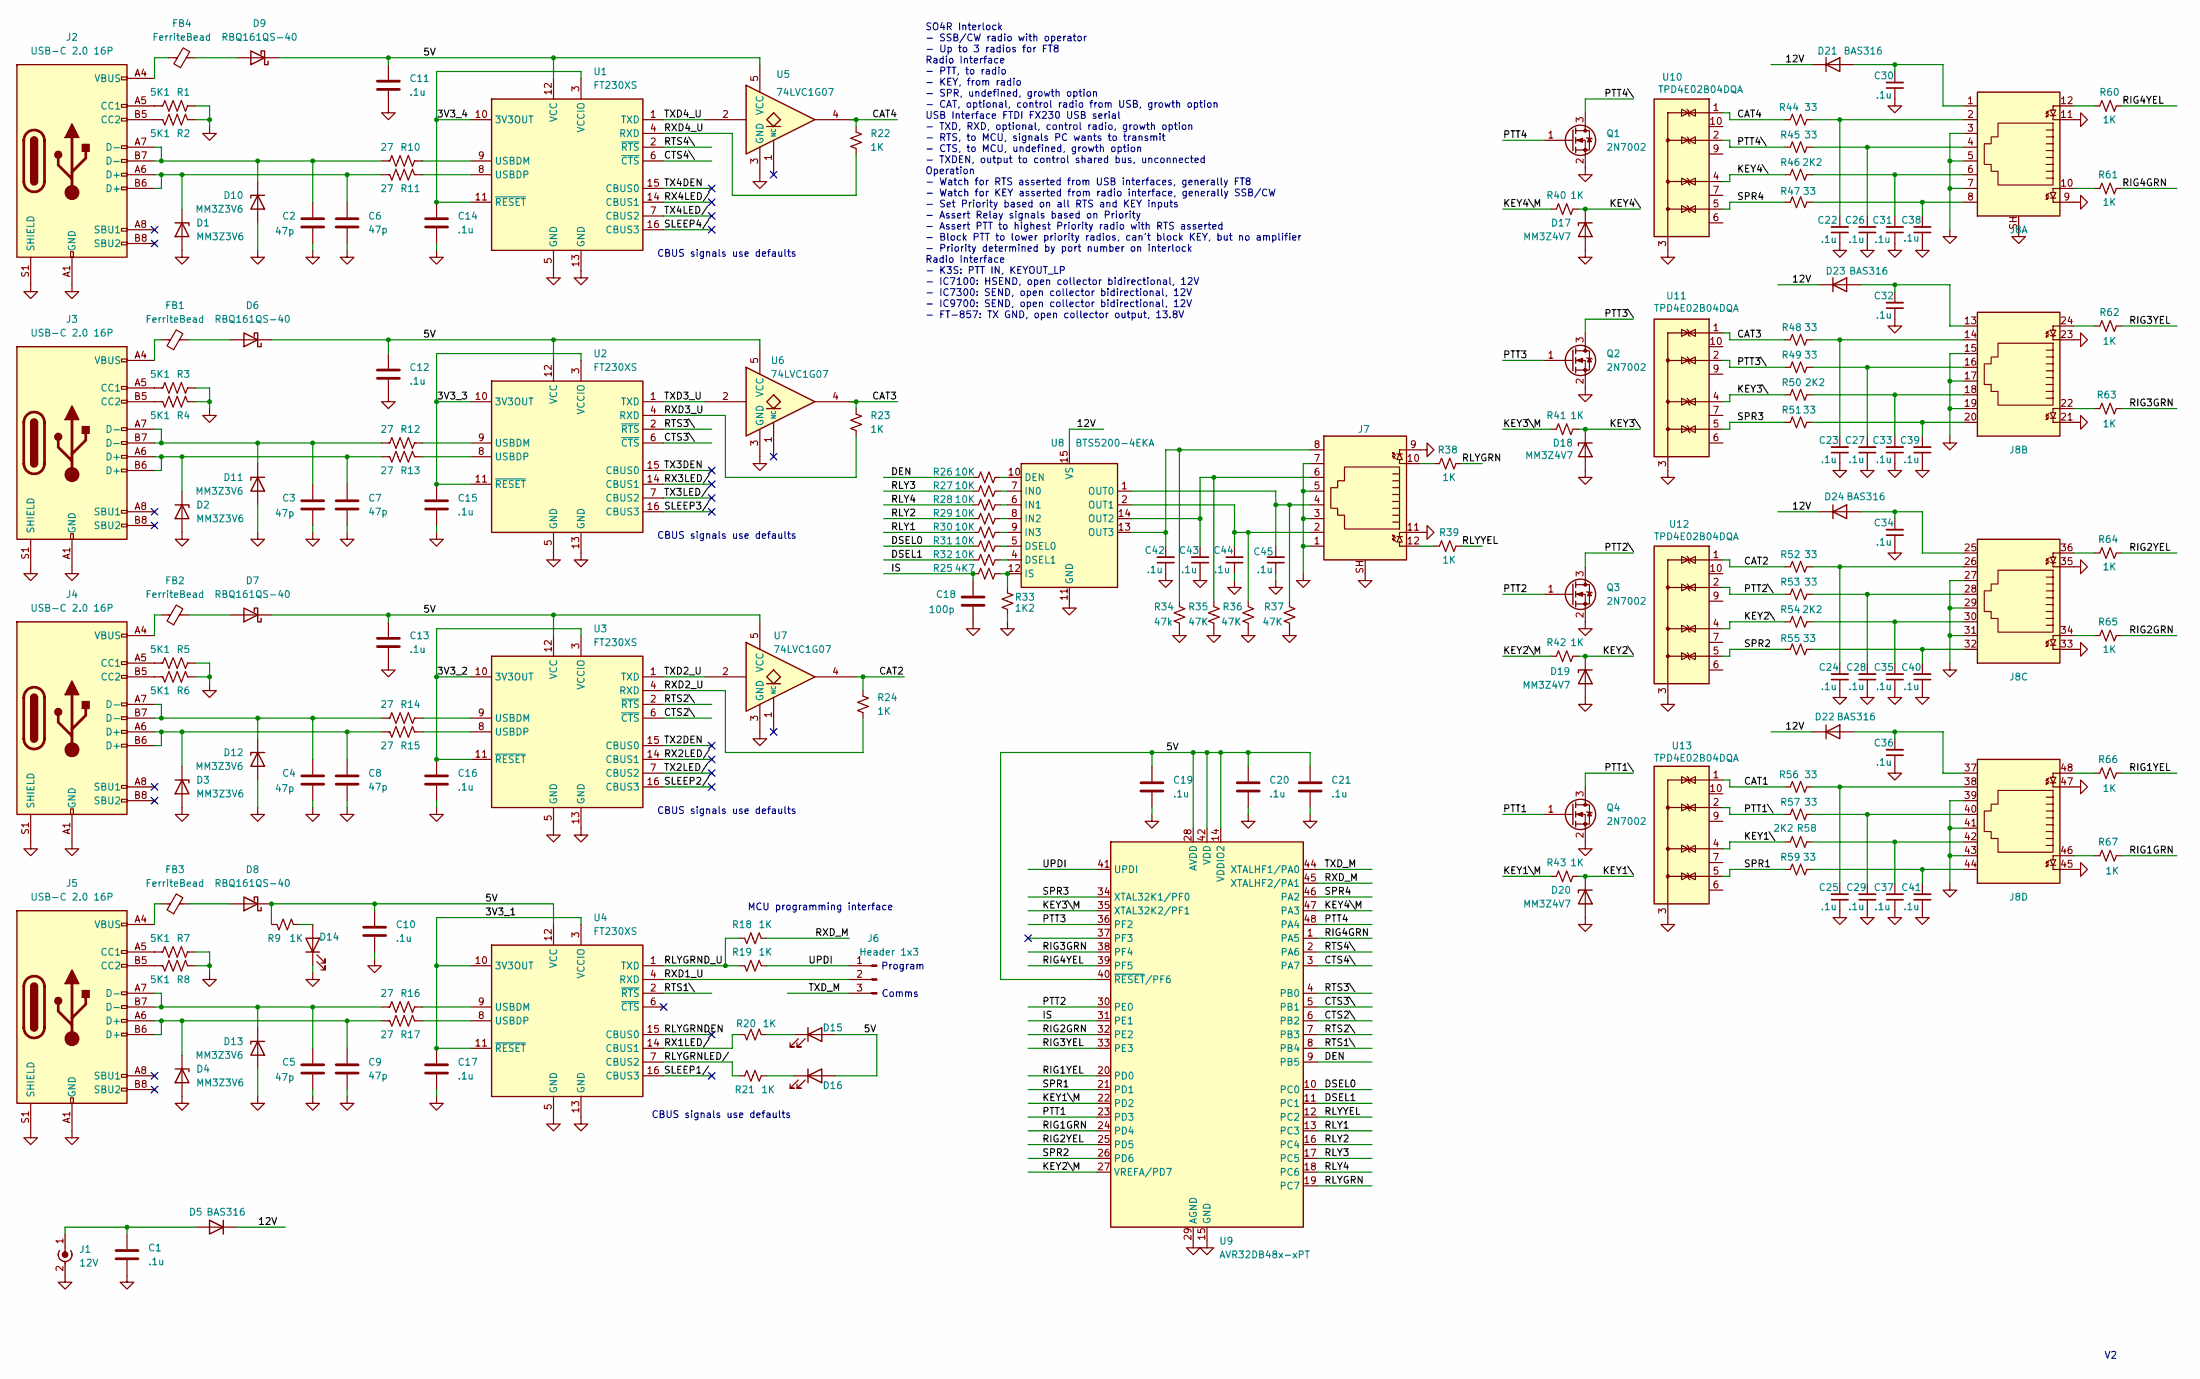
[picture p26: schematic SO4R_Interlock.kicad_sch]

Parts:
C1, C10, C11, C12, C13, C14, C15, C16, C17, C19, C20, C21: .1u; C_0402_1005Metric; LCSC PN C15849
C2, C3, C4, C5, C6, C7, C8, C9: 47p; C_0402_1005Metric; LCSC PN C1671
C18: 100p; C_0402_1005Metric; LCSC PN C1671
C22, C23, C24, C25, C26, C27, C28, C29, C30, C31, C32, C33, C34, C35, C36, C37, C38, C39, C40, C41, C42, C43, C44, C45: .1u; C_0402_1005Metric
D1, D2, D3, D4, D10, D11, D12, D13: MM3Z3V6; D_SOD-323; LCSC PN C19077454
D5, D21, D22, D23, D24: BAS316; D_SOD-323
D6, D7, D8, D9: RBQ161QS-40; D_0402_1005Metric
D14: Green; LED_0603_1608Metric; LCSC PN C22371299
D15, D16: Yellow; LED_0603_1608Metric; LCSC PN C72038
D17, D18, D19, D20: MM3Z4V7; D_SOD-323; LCSC C116949
FB1, FB2, FB3, FB4: FerriteBead; L_0805_2012Metric; LCSC PN C1017
J1: 12V; BarrelJack_Kycon_KLDX-0202-xC_Horizontal
J2, J3, J4, J5: USB-C 2.0 16P; USB_C_Receptacle_G-Switch_GT-USB-7010ASV; LCSC PN C2835315
J6: Header 1x3; PinHeader_1x03_P2.54mm_Vertical; LCSC PN C6332196
J7: RJ45_LED_Shielded; RJ45_Amphenol_RJHSE538X
J8: 8P8C_LED_Shielded_x4; RJ45_Amphenol_RJHSE538X-04
Q1, Q2, Q3, Q4: 2N7002; SOT-23
R1, R2, R3, R4, R5, R6, R7, R8: 5K1; R_0402_1005Metric; LCSC PN C23186
R9, R18, R19, R20, R21: 1K; R_0402_1005Metric; LCSC PN C21190
R10, R11, R12, R13, R14, R15, R16, R17: 27; R_0402_1005Metric; LCSC PN C25190
R22, R23, R24, R38, R39, R60, R61, R62, R63, R64, R65, R66, R67: 1K; R_0402_1005Metric
R25: 4K7; R_0402_1005Metric
R26, R27, R28, R29, R30, R31, R32: 10K; R_0402_1005Metric
R33: 1K2; R_0402_1005Metric
R34: 47k; R_0402_1005Metric
R35, R36, R37: 47K; R_0402_1005Metric
R40, R41, R42, R43: 1K; R_0402_1005Metric; LCSC C21190
R44, R45, R47, R48, R49, R51, R52, R53, R55, R56, R57, R59: 33; R_0402_1005Metric
R46, R50, R54, R58: 2K2; R_0402_1005Metric; LCSC C113303
U1, U2, U3, U4: FT230XS; SSOP-16_3.9x4.9mm_P0.635mm; LCSC PN C69082
U5, U6, U7: 74LVC1G07; SOT-23-5
U8: BTS5200-4EKA; Infineon_PG-DSO-14-48-EP
U9: AVR32DB48x-xPT; TQFP-48_7x7mm_P0.5mm
U10, U11, U12, U13: TPD4E02B04DQA; USON-10_2.5x1.0mm_P0.5mm

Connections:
/3V3_1: C17.1, U4.3 (VCCIO), U4.10 (3V3OUT), U4.11 (~RESET)
/3V3_2: C16.1, U3.3 (VCCIO), U3.10 (3V3OUT), U3.11 (~RESET)
/3V3_3: C15.1, U2.3 (VCCIO), U2.10 (3V3OUT), U2.11 (~RESET)
/3V3_4: C14.1, U1.3 (VCCIO), U1.10 (3V3OUT), U1.11 (~RESET)
/5V: C10.1, C11.1, C12.1, C13.1, C19.1, C20.1, C21.1, D6.1 (K), D7.1 (K), D8.1 (K), D9.1 (K), D15.2 (A), D16.2 (A), R9.2, U1.12 (VCC), U2.12 (VCC), U3.12 (VCC), U4.12 (VCC), U5.5 (VCC), U6.5 (VCC), U7.5 (VCC), U9.14 (VDDIO2), U9.28 (AVDD), U9.40 (~RESET/PF6), U9.42 (VDD)
/12V: D5.1 (K), D21.1 (K), D22.1 (K), D23.1 (K), D24.1 (K), U8.15 (VS)
/CAT1: R56.1, U13.1 (IO1)
/CAT2: R24.1, R52.1, U7.4, U12.1 (IO1)
/CAT3: R23.1, R48.1, U6.4, U11.1 (IO1)
/CAT4: R22.1, R44.1, U5.4, U10.1 (IO1)
/CTS2\: U3.6 (~CTS), U9.6 (PB2)
/CTS3\: U2.6 (~CTS), U9.5 (PB1)
/CTS4\: U1.6 (~CTS), U9.3 (PA7)
/DEN: R26.1, U9.9 (PB5)
/DSEL0: R31.1, U9.10 (PC0)
/DSEL1: R32.1, U9.11 (PC1)
/IS: C18.1, R25.1, U9.31 (PE1)
/KEY1\: D20.1 (K), R43.1, R58.2, U13.4 (IO3)
/KEY1\M: R43.2, U9.22 (PD2)
/KEY2\: D19.1 (K), R42.1, R54.2, U12.4 (IO3)
/KEY2\M: R42.2, U9.27 (VREFA/PD7)
/KEY3\: D18.1 (K), R41.1, R50.2, U11.4 (IO3)
/KEY3\M: R41.2, U9.35 (XTAL32K2/PF1)
/KEY4\: D17.1 (K), R40.1, R46.2, U10.4 (IO3)
/KEY4\M: R40.2, U9.47 (PA3)
/PTT1: Q4.1 (G), U9.23 (PD3)
/PTT1\: Q4.3 (D), R57.1, U13.2 (IO2)
/PTT2: Q3.1 (G), U9.30 (PE0)
/PTT2\: Q3.3 (D), R53.1, U12.2 (IO2)
/PTT3: Q2.1 (G), U9.36 (PF2)
/PTT3\: Q2.3 (D), R49.1, U11.2 (IO2)
/PTT4: Q1.1 (G), U9.48 (PA4)
/PTT4\: Q1.3 (D), R45.1, U10.2 (IO2)
/RIG1GRN: R67.2, U9.24 (PD4)
/RIG1YEL: R66.2, U9.20 (PD0)
/RIG2GRN: R65.2, U9.32 (PE2)
/RIG2YEL: R64.2, U9.25 (PD5)
/RIG3GRN: R63.2, U9.38 (PF4)
/RIG3YEL: R62.2, U9.33 (PE3)
/RIG4GRN: R61.2, U9.1 (PA5)
/RIG4YEL: R60.2, U9.39 (PF5)
/RLY1: R30.1, U9.13 (PC3)
/RLY2: R29.1, U9.16 (PC4)
/RLY3: R27.1, U9.17 (PC5)
/RLY4: R28.1, U9.18 (PC6)
/RLYGRN: R38.2, U9.19 (PC7)
/RLYGRNDEN: U4.15 (CBUS0)
/RLYGRND_U: R18.1, R19.1, U4.1 (TXD)
/RLYGRNLED/: R21.1, U4.7 (CBUS2)
/RLYYEL: R39.2, U9.12 (PC2)
/RTS1\: U4.2 (~RTS), U9.8 (PB4)
/RTS2\: U3.2 (~RTS), U9.7 (PB3)
/RTS3\: U2.2 (~RTS), U9.4 (PB0)
/RTS4\: U1.2 (~RTS), U9.2 (PA6)
/RX1LED/: R20.1, U4.14 (CBUS1)
/RX2LED/: U3.14 (CBUS1)
/RX3LED/: U2.14 (CBUS1)
/RX4LED/: U1.14 (CBUS1)
/RXD1_U: J6.2, U4.4 (RXD)
/RXD2_U: R24.2, U3.4 (RXD)
/RXD3_U: R23.2, U2.4 (RXD)
/RXD4_U: R22.2, U1.4 (RXD)
/RXD_M: R18.2, U9.45 (XTALHF2/PA1)
/SLEEP1/: U4.16 (CBUS3)
/SLEEP2/: U3.16 (CBUS3)
/SLEEP3/: U2.16 (CBUS3)
/SLEEP4/: U1.16 (CBUS3)
/SPR1: R59.1, U9.21 (PD1), U13.5 (IO4)
/SPR2: R55.1, U9.26 (PD6), U12.5 (IO4)
/SPR3: R51.1, U9.34 (XTAL32K1/PF0), U11.5 (IO4)
/SPR4: R47.1, U9.46 (PA2), U10.5 (IO4)
/TX2DEN: U3.15 (CBUS0)
/TX2LED/: U3.7 (CBUS2)
/TX3DEN: U2.15 (CBUS0)
/TX3LED/: U2.7 (CBUS2)
/TX4DEN: U1.15 (CBUS0)
/TX4LED/: U1.7 (CBUS2)
/TXD2_U: U3.1 (TXD), U7.2
/TXD3_U: U2.1 (TXD), U6.2
/TXD4_U: U1.1 (TXD), U5.2
/TXD_M: J6.3, U9.44 (XTALHF1/PA0)
/UPDI: J6.1, R19.2, U9.41 (UPDI)
GND: C1.2, C2.2, C3.2, C4.2, C5.2, C6.2, C7.2, C8.2, C9.2, C10.2, C11.2, C12.2, C13.2, C14.2, C15.2, C16.2, C17.2, C18.2, C19.2, C20.2, C21.2, C22.1, C23.1, C24.1, C25.1, C26.1, C27.1, C28.1, C29.1, C30.1, C31.1, C32.1, C33.1, C34.1, C35.1, C36.1, C37.1, C38.1, C39.1, C40.1, C41.1, C42.1, C43.1, C44.1, C45.1, D1.2 (A), D2.2 (A), D3.2 (A), D4.2 (A), D10.2 (A), D11.2 (A), D12.2 (A), D13.2 (A), D14.1 (K), D17.2 (A), D18.2 (A), D19.2 (A), D20.2 (A), J1.2 (Ext), J2.A1 (GND), J2.A12 (GND), J2.B1 (GND), J2.B12 (GND), J2.S1 (SHIELD), J3.A1 (GND), J3.A12 (GND), J3.B1 (GND), J3.B12 (GND), J3.S1 (SHIELD), J4.A1 (GND), J4.A12 (GND), J4.B1 (GND), J4.B12 (GND), J4.S1 (SHIELD), J5.A1 (GND), J5.A12 (GND), J5.B1 (GND), J5.B12 (GND), J5.S1 (SHIELD), J7.1, J7.3, J7.5, J7.7, J7.9, J7.11, J7.SH, J8.3, J8.5, J8.7, J8.9, J8.11, J8.15, J8.17, J8.19, J8.21, J8.23, J8.27, J8.29, J8.31, J8.33, J8.35, J8.39, J8.41, J8.43, J8.45, J8.47, J8.SH, Q1.2 (S), Q2.2 (S), Q3.2 (S), Q4.2 (S), R1.1, R2.1, R3.1, R4.1, R5.1, R6.1, R7.1, R8.1, R33.2, R34.2, R35.2, R36.2, R37.2, U1.5 (GND), U1.13 (GND), U2.5 (GND), U2.13 (GND), U3.5 (GND), U3.13 (GND), U4.5 (GND), U4.13 (GND), U5.3 (GND), U6.3 (GND), U7.3 (GND), U8.11 (GND), U9.15 (GND), U9.29 (AGND), U9.43 (GND), U10.3 (G), U10.8 (G), U11.3 (G), U11.8 (G), U12.3 (G), U12.8 (G), U13.3 (G), U13.8 (G)
unnamed: C22.2, J8.2, R44.2
unnamed: C23.2, J8.14, R48.2
unnamed: C24.2, J8.26, R52.2
unnamed: C25.2, J8.38, R56.2
unnamed: C26.2, J8.4, R45.2
unnamed: C27.2, J8.16, R49.2
unnamed: C28.2, J8.28, R53.2
unnamed: C29.2, J8.40, R57.2
unnamed: C31.2, J8.6, R46.1
unnamed: C33.2, J8.18, R50.1
unnamed: C35.2, J8.30, R54.1
unnamed: C37.2, J8.42, R58.1
unnamed: C38.2, J8.8, R47.2
unnamed: C39.2, J8.20, R51.2
unnamed: C40.2, J8.32, R55.2
unnamed: C41.2, J8.44, R59.2
unnamed: C6.1, D1.1 (K), J2.A6 (D+), J2.B6 (D+), R11.2
unnamed: C7.1, D2.1 (K), J3.A6 (D+), J3.B6 (D+), R13.2
unnamed: C8.1, D3.1 (K), J4.A6 (D+), J4.B6 (D+), R15.2
unnamed: C9.1, D4.1 (K), J5.A6 (D+), J5.B6 (D+), R17.2
unnamed: C1.1, D5.2 (A), J1.1 (In)
unnamed: D6.2 (A), FB1.2
unnamed: D7.2 (A), FB2.2
unnamed: D8.2 (A), FB3.2
unnamed: D9.2 (A), FB4.2
unnamed: C2.1, D10.1 (K), J2.A7 (D-), J2.B7 (D-), R10.2
unnamed: C3.1, D11.1 (K), J3.A7 (D-), J3.B7 (D-), R12.2
unnamed: C4.1, D12.1 (K), J4.A7 (D-), J4.B7 (D-), R14.2
unnamed: C5.1, D13.1 (K), J5.A7 (D-), J5.B7 (D-), R16.2
unnamed: D14.2 (A), R9.1
unnamed: D15.1 (K), R20.2
unnamed: D16.1 (K), R21.2
unnamed: C30.2, D21.2 (A), J8.1
unnamed: C36.2, D22.2 (A), J8.37
unnamed: C32.2, D23.2 (A), J8.13
unnamed: C34.2, D24.2 (A), J8.25
unnamed: FB1.1, J3.A4 (VBUS), J3.A9 (VBUS), J3.B4 (VBUS), J3.B9 (VBUS)
unnamed: FB2.1, J4.A4 (VBUS), J4.A9 (VBUS), J4.B4 (VBUS), J4.B9 (VBUS)
unnamed: FB3.1, J5.A4 (VBUS), J5.A9 (VBUS), J5.B4 (VBUS), J5.B9 (VBUS)
unnamed: FB4.1, J2.A4 (VBUS), J2.A9 (VBUS), J2.B4 (VBUS), J2.B9 (VBUS)
unnamed: J2.A5 (CC1), R1.2
unnamed: J2.B5 (CC2), R2.2
unnamed: J3.A5 (CC1), R3.2
unnamed: J3.B5 (CC2), R4.2
unnamed: J4.A5 (CC1), R5.2
unnamed: J4.B5 (CC2), R6.2
unnamed: J5.A5 (CC1), R7.2
unnamed: J5.B5 (CC2), R8.2
unnamed: J7.10, R38.1
unnamed: J7.12, R39.1
unnamed: J8.10, R61.1
unnamed: J8.12, R60.1
unnamed: J8.22, R63.1
unnamed: J8.24, R62.1
unnamed: J8.34, R65.1
unnamed: J8.36, R64.1
unnamed: J8.46, R67.1
unnamed: J8.48, R66.1
unnamed: R10.1, U1.9 (USBDM)
unnamed: R11.1, U1.8 (USBDP)
unnamed: R12.1, U2.9 (USBDM)
unnamed: R13.1, U2.8 (USBDP)
unnamed: R14.1, U3.9 (USBDM)
unnamed: R15.1, U3.8 (USBDP)
unnamed: R16.1, U4.9 (USBDM)
unnamed: R17.1, U4.8 (USBDP)
unnamed: R26.2, U8.10 (DEN)
unnamed: R31.2, U8.5 (DSEL0)
unnamed: R32.2, U8.4 (DSEL1)
unnamed: R27.2, U8.7 (IN0)
unnamed: R28.2, U8.6 (IN1)
unnamed: R29.2, U8.8 (IN2)
unnamed: R30.2, U8.9 (IN3)
unnamed: R25.2, R33.1, U8.12 (IS)
unnamed: C45.2, J7.4, R37.1, U8.1 (OUT0)
unnamed: C44.2, J7.2, R36.1, U8.2 (OUT1)
unnamed: C43.2, J7.6, R35.1, U8.14 (OUT2)
unnamed: C42.2, J7.8, R34.1, U8.13 (OUT3)

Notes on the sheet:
SO4R Interlock - SSB/CW radio with operator - Up to 3 radios for FT8 Radio Interface - PTT, to radio - KEY, from radio - SPR, undefined, growth option - CAT, optional, control radio from USB, growth option USB Interface FTDI FX230 USB serial - TXD, RXD, optional, control radio, growth option - RTS,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
CBUS signals use defaults
Program
MCU programming interface
Comms

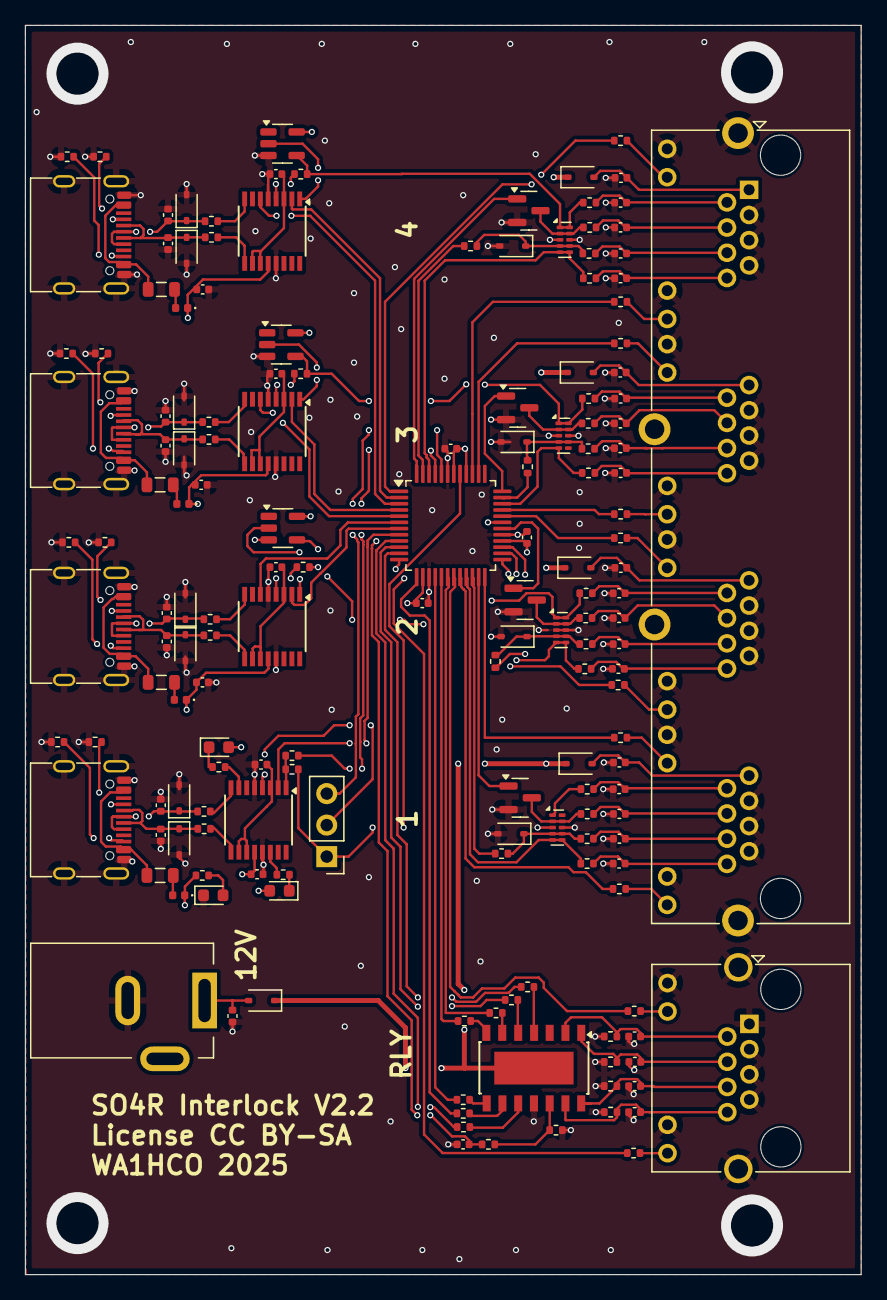
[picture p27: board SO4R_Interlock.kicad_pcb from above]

Board: 4 copper layers, 67.4 x 100.7 mm, 165 parts (0 on the bottom side), 147 nets.

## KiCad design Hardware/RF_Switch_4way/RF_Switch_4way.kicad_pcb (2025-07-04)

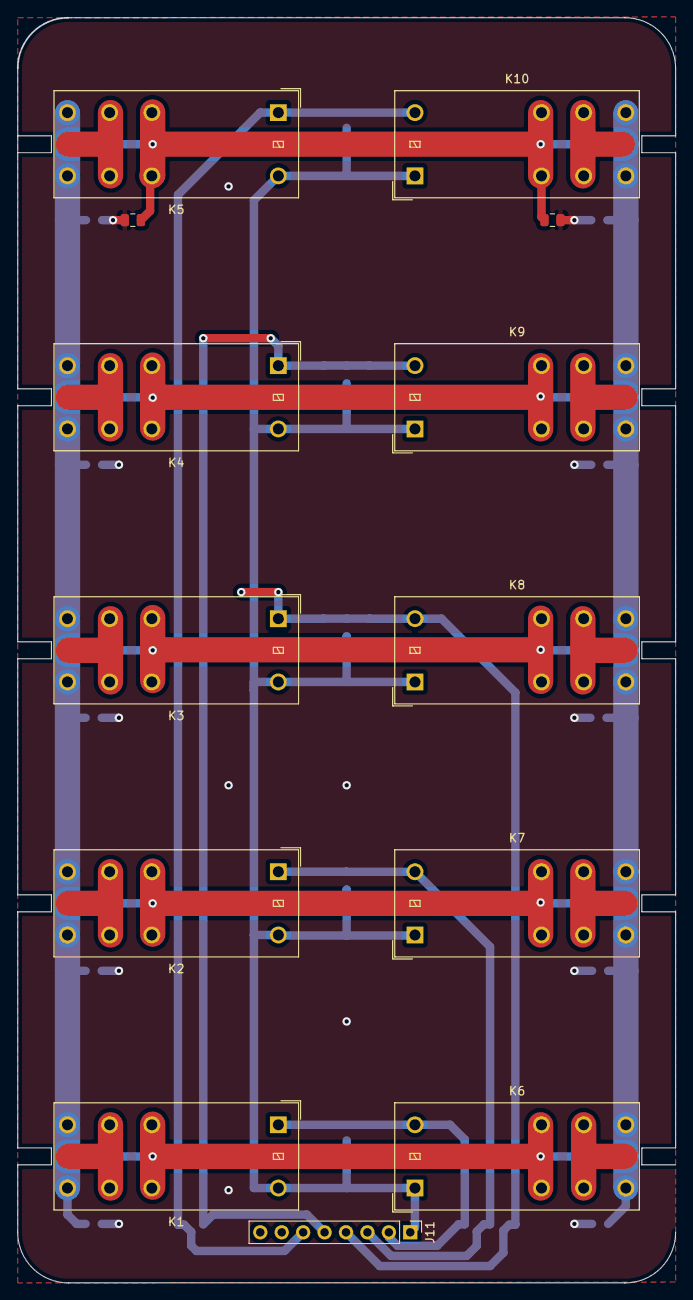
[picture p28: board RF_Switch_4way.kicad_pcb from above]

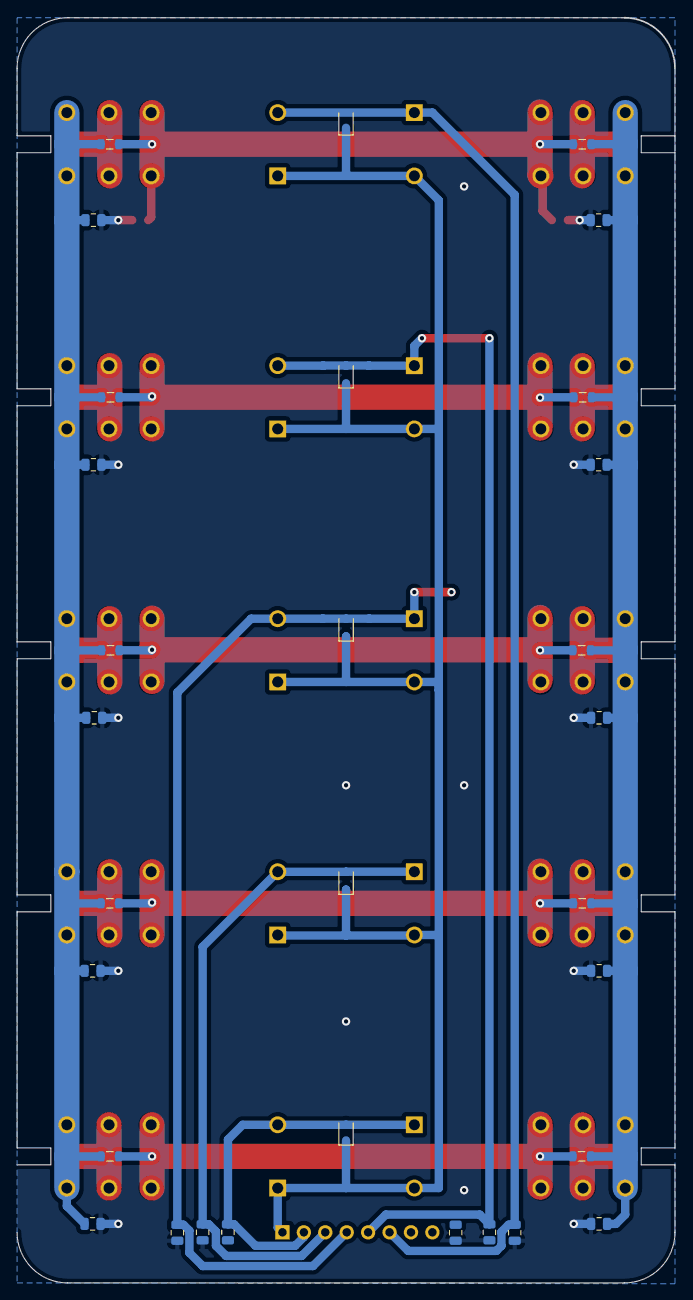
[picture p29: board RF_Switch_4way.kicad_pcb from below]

Board: 2 copper layers, 78.0 x 150.0 mm, 44 parts (31 on the bottom side), 14 nets.

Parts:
C1, C2, C3, C4, C5, C9, C10, C18, C20, C21, C22, C24: 5p; C_0805_2012Metric
C6, C7, C8, C14, C15, C16: .01; C_0805_2012Metric
D1, D2, D3, D4, D5: D; D_SOD-323
J11: Conn_01x08_Pin; PinHeader_1x08_P2.54mm_Vertical
K1, K2, K3, K4, K5, K6, K7, K8, K9, K10: G2RL-1-E; Relay_SPDT_Omron_G2RL-1-E
L1, L2, L3, L4, L5, L6, L7, L8, L9, L10: L_Small; L_0805_2012Metric

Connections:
/12V: C14.1, D1.1 (K), D2.1 (K), D3.1 (K), D4.1 (K), D5.1 (K), J11.1, K1.A2, K2.A2, K3.A2, K4.A2, K5.A2, K6.A1, K7.A1, K8.A1, K9.A1, K10.A1
/Amplifier\: C15.1, D5.2 (A), J11.6, K5.A1, K10.A2
/Radio_1\: C8.1, D1.2 (A), J11.2, K1.A1, K6.A2
/Radio_2\: C7.1, D2.2 (A), J11.3, K2.A1, K7.A2
/Radio_3\: C6.1, D3.2 (A), J11.4, K3.A1, K8.A2
/Radio_4\: C16.1, D4.2 (A), J11.5, K4.A1, K9.A2
GND: C1.2, C2.2, C3.2, C4.2, C5.2, C6.2, C7.2, C8.2, C9.2, C10.2, C14.2, C15.2, C16.2, C18.2, C20.2, C21.2, C22.2, C24.2
unnamed: C1.1, C2.1, C3.1, C4.1, C5.1, K6.14, K7.14, K8.14, K9.14, K10.14, L1.1, L2.1, L3.1, L4.1, L5.1
unnamed: C9.1, C10.1, K5.12, K10.12, L5.2, L10.1
unnamed: C18.1, C20.1, C21.1, C22.1, C24.1, K1.14, K2.14, K3.14, K4.11, K4.14, K5.14, L6.2, L7.2, L8.2, L9.2, L10.2
unnamed: K1.12, K6.12, L1.2, L6.1
unnamed: K2.12, K7.12, L2.2, L7.1
unnamed: K3.12, K8.12, L3.2, L8.1
unnamed: K4.12, K9.12, L4.2, L9.1

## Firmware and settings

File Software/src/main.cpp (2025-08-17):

// SO4R Interlock control program for V2 hardware
// Function
//   Multiple radios interoperating on the same band
//   Baseline, one SSB/CW radio, up to 3 WSJTX radios
//   WSJTX radios listen on 3 wide spaced antenna, separte directions
//   3 radios can hear when 1 radio transmitting
//   Only one radio can transmit at a time
//   SSb/CW operation has priority and can instantlly inhibit WSJTX TX
//   WSJTX radios listen in 3 directions
//   WSJTX sends stations heard to combined list for review by SSB/CW op
//   Interlock detects SSB/CW Tx by reading KEY line from radio
//   Interlock detects WSJTX Tx by reading RTS line from USB interface
//   Interlock forwards RTS signal from USB to radio interface

// Interlock ensures 
//   only one signal transmitted at a time
//   Stay within ARRL VHF contest rules
//   Sequencing to prevent hot switching
// Transmitting radio is routed through a single amplifier

// Interlock hardware description
//   4 USB serial ports that support CAT and RTS
//   4 Radio control ports that support PTT, KEY, CAT, Spare
//   4 relay control ports for transfer relays and dual 4:1 Mux (for amplifier)

// Interlock software description
//   Read RTS (Tx requests) and KEY {radio Tx'ing}
//   Compute Priority, 0 Rx (no Tx), 1 SSB/CW, 2, 3, 4 WSJTX
//   if RTS or KEY, assert PTT and Relay to highest priority radio

#include <HardwareConfig.h>

void setup() {
  Serial.begin(9600);
  Serial.available();
  ConfigPins(); // configure the I/O pins
 
  // all Tx off
  digitalWrite(   PTT1PIN,    false);  // Radio 1 PTT, generally not used
  digitalWrite(   PTT2PIN,    false);  // Radio 2 PTT
  digitalWrite(   PTT3PIN,    false);  // Radio 3 PTT
  digitalWrite(   PTT4PIN,    false);  // Radio 4 PTT

  // all relays off
  digitalWrite(   RLY1PIN,    false);  // Priority 1 Relays, SSB/CW radio
  digitalWrite(   RLY2PIN,    false);  // Priority 2 Relays, WSJTX radio
  digitalWrite(   RLY3PIN,    false);  // Priority 3 Relays, WSJTX radio
  digitalWrite(   RLY4PIN,    false);  // Priority 4 Relays, WSJTX radio

  // all LEDs on RJ45 off
  digitalWrite(   RIG1GRNPIN, false);
  digitalWrite(   RIG1YELPIN, false);
  digitalWrite(   RIG2GRNPIN, false);
  digitalWrite(   RIG2YELPIN, false);
  digitalWrite(   RIG3GRNPIN, false);
  digitalWrite(   RIG3YELPIN, false);
  digitalWrite(   RIG4GRNPIN, false);
  digitalWrite(   RIG4YELPIN, false);

  // CTS\ from MCU to USB chip not asserted
  digitalWrite(  CTS2nPIN,    true);
  digitalWrite(  CTS3nPIN,    true);
  digitalWrite(  CTS4nPIN,    true);

  // light the leds in a ripple, leave them off at the end
  #define LED_DELAY 30
  for(byte ii = 0; ii < 2; ii ++) {
    digitalWrite( RLYYELPIN,  true);  delay(LED_DELAY);
    digitalWrite( RLYYELPIN,  false); delay(LED_DELAY);
    digitalWrite( RLYGRNPIN,  true);  delay(LED_DELAY);
    digitalWrite( RLYGRNPIN,  false); delay(LED_DELAY);

    digitalWrite( RIG1YELPIN, true);  delay(LED_DELAY);
    digitalWrite( RIG1YELPIN, false); delay(LED_DELAY);
    digitalWrite( RIG1GRNPIN, true);  delay(LED_DELAY);
    digitalWrite( RIG1GRNPIN, false); delay(LED_DELAY);

    digitalWrite( RIG2YELPIN, true);  delay(LED_DELAY);
    digitalWrite( RIG2YELPIN, false); delay(LED_DELAY);
    digitalWrite( RIG2GRNPIN, true);  delay(LED_DELAY);
    digitalWrite( RIG2GRNPIN, false); delay(LED_DELAY);

    digitalWrite( RIG3YELPIN, true);  delay(LED_DELAY); 
    digitalWrite( RIG3YELPIN, false); delay(LED_DELAY);
    digitalWrite( RIG3GRNPIN, true);  delay(LED_DELAY);
    digitalWrite( RIG3GRNPIN, false); delay(LED_DELAY);

    digitalWrite( RIG4YELPIN, true);  delay(LED_DELAY);
    digitalWrite( RIG4YELPIN, false); delay(LED_DELAY);
    digitalWrite( RIG4GRNPIN, true);  delay(LED_DELAY);
    digitalWrite( RIG4GRNPIN, false); delay(LED_DELAY);

    // defaults for the relay driver diagnostic function
    digitalWrite( DSEL0PIN,   false);
    digitalWrite( DSEL1PIN,   false);
    digitalWrite( DENPIN,     false);
  }
}

// Inputs
//   RTS\ from USB, when WSJTX wants to transmit
//   KEY\ from radio, when radio keyed by PTT or manually
// Outputs
//   PTT to radio, when needing to transmit and highest priority
//   RLYn to relays, when controlling which radio uses amplifier
//   TX LED, on RJ45 connector for each radio interface, indicates TX and has amplifier
//   INH LED, on RJ45 connector for each radio interface, indicates wants to TX but not highest priority
// Operation
//   Read RTS and KEY IO and save to variables for speed
//   Compute the Priority from all Tx requests
//   Assert PTT to radio if RTS asserted for WSJTX radios and highest priority
//   Assert RLY to relays if KEY asserted from SSB/CW radio
//   Assert green led to radio interface if PTT and highest priority 
//   Assert yellow LED to radio interface if KEY asserted or PTT and not highest priority

// Explicit sequencing operation not need in Interlock
//   Rx to Tx
//     On assertion of PTT, KEY output from radio asserted immediately
//     Radio delays RF output to allow relays connected to KEY to operate
//     Interlock picks up RTS for WSJT or KEY from SSB/CW and immediately asserts relays
//     Relays controlled by Interlock are no different from conventional amplifier
//     Radio delays RF, so no sequencing steps needed for Rx to Tx
//   Tx to Rx
//     On release of PTT, RF generation stops immediately
//     RF passing through 2.5 KHz filters is delayed less than 1 msec
//     KEY released immediately
//     Interlock releases relays immediately
//     Relays hold for few msec, so not hot switched on release of PTT

// Corner case
//  Operator presses Tx button on WSJT radio
//    Radio goes into transmit, but not allowed to use amplifier or relays
//    Interlock see the KEY and lights the yellow LED on the radio RJ45
//    Transfer relays remain in pass thru to antenna

// Timing of Interlock software
//   On every pass through loop() function
//     Read PTT and KEY signals and save to variables
//     Interlock sees new transmit signal in less than TBD usec (50 usec?)
//   Determine priority from both RTS and KEY signals
//     0 means Rx, 1 for SSB/CW, 2, 3, 4 for WSJTX
//   Copy Priority signal from radio to relays
//     if lower priority, set relays to RX
//     if highest priority, set relays to TX, thru amplifier
//   For each RTS and PTT pair, copy RTS signal from USB serial port to PTT radio interface
//     If no RTS asserted, PTT not asserted
//     If RTS asserted, but not highest priority, PTT not asserted
//     If RTS asserted and highest priority, PTT asserted
//   Benefits of this algorithm
//     Priority determined from SSB/CW KEY and WSJT RTS
//     RTS from WSJT immediately controls PTT 
//       RTS assertion at highest priority immediately asserts PTT
//       RTS assertion at highest priority also updates priority
//       RTS release immediately releases PTT
//     KEY from SSB/CW radio controls relays (as intended by the radio manufacturers)

void loop() {
  int Priority;

  // Read inputs, invert from low true to high true logic
  // RTS1 not used to prevent keying on programming or serial I/O
  bool RTS2 = !digitalRead(RTS2nPIN); // RTS from serial port asks for Tx
  bool RTS3 = !digitalRead(RTS3nPIN);
  bool RTS4 = !digitalRead(RTS4nPIN);  

  // KEY 2,3,4
  //    Not used for relays to prevent sequencing error if operator presses TX on radio
  //    Used to light yellow LED on radio interface
  bool KEY1 = !digitalRead(KEY1nPIN); // KEY from radio says Tx from RTS or manual
  bool KEY2 = !digitalRead(KEY2nPIN); // KEY from radio says Tx from RTS or manual
  bool KEY3 = !digitalRead(KEY3nPIN); // KEY from radio says Tx from RTS or manual
  bool KEY4 = !digitalRead(KEY4nPIN); // KEY from radio says Tx from RTS or manual

  // Compute Priority based on RTS and KEY inputs
  // If no Tx requests, remains at 0 (Rx)
  Priority = 0;            // Rx mode
  if (RTS4) Priority = 4;  // WSJTX radio
  if (RTS3) Priority = 3;  // WSJTX radio
  if (RTS2) Priority = 2;  // WSJTX radio
  if (KEY1) Priority = 1;  // SSB/CW radio

  // Output signals in order of timing criticality

  // Assert Tx to relays 
  // Use priority set from RTS and KEY
  // Relays asserted if either RTS or KEY input and priority
  bool RLY1 = (Priority == 1);
  bool RLY2 = (Priority == 2);
  bool RLY3 = (Priority == 3);
  bool RLY4 = (Priority == 4);
  digitalWrite(RLY1PIN, RLY1);
  digitalWrite(RLY2PIN, RLY2);
  digitalWrite(RLY3PIN, RLY3);
  digitalWrite(RLY4PIN, RLY4);

  // Assert PTT to radios with RTS and corresponding to priority, all others stay Rx
  // PTT asserted only on RTS and priority, do not use KEY
  // SSB/CW radio doesn't need PTT from Interlock
  bool PTT2 = RTS2 and (Priority == 2);
  bool PTT3 = RTS3 and (Priority == 3);
  bool PTT4 = RTS4 and (Priority == 4);
  digitalWrite(PTT2PIN, PTT2);
  digitalWrite(PTT3PIN, PTT3);
  digitalWrite(PTT4PIN, PTT4);

  // Assert Rig RJ45 Green LED if rig is transmitting
  digitalWrite(RIG1GRNPIN,  RLY1);
  digitalWrite(RIG2GRNPIN,  RLY2);
  digitalWrite(RIG3GRNPIN,  RLY3);
  digitalWrite(RIG4GRNPIN,  RLY4);

  // Assert Rig RJ45 Yellow LED if 
  //  WSJT asking for Tx but not highest priority
  //  Radio indicates KEY without RTS, meaning operator pressed TX button
  bool INH2 = (RTS2 and (Priority > 0) and (Priority < 2)) or (KEY2 and !RTS2);
  bool INH3 = (RTS3 and (Priority > 0) and (Priority < 3)) or (KEY3 and !RTS3);
  bool INH4 = (RTS4 and (Priority > 0) and (Priority < 4)) or (KEY4 and !RTS4);
  digitalWrite(RIG2YELPIN, INH2); 
  digitalWrite(RIG3YELPIN, INH3);
  digitalWrite(RIG4YELPIN, INH4);

  // Assert Relay RJ45 Green LED if any rig transmitting
  // Assert Relay RJ45 Yellow LED if any rig inhibited
  digitalWrite(RLYGRNPIN, (Priority > 0));
  digitalWrite(RLYYELPIN, INH2 or INH3 or INH4);
} 

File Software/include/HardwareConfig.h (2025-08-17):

#ifndef HardwareConfig_h
#define HardwareConfig_h
// Hardware configuration from the V1 schematic
#include <Arduino.h> // get the pin names

// AVR32DB48, Hardware Pin Definitions, lower case means secondary pin location
//-----|--------|----------|------|-------|--------|-------|-----|--------|--------|
// Pin | Name   | Function | Free | Power | Serial | ADC   | DAC |  SPI   |  TWI   |
//-----|--------|----------|------|-------|--------|-------|-----|--------|--------|
//  1  | PA5    | RIG4GRN  |      |       | 0,rxd  |       |     |        |        |
//  2  | PA6    | RTS4\    |      |       | 0,xck  |       |     | 0,MOSI |        |
//  3  | PA7    | CTS4\    |      |       | 0,xdir |       |     | 0,MISO |        |
//  4  | PB0    | RTS3\    |      |       | 3,TXD  |       |     | 0,SCK  |        |
//  5  | PB1    | CTS3\    |      |       | 3,RXD  |       |     | 0,SS\  |        |
//  6  | PB2    | CTS2\    |      |       | 3,XCK  |       |     |        | 1,sda  |
//  7  | PB3    | RTS2\    |      |       | 3,XDIR |       |     |        | 1,scl  |
//  8  | PB4    | RTS1\    |      |       | 3,txd  |       |     |        |        |
//  9  | PB5    | DEN      |      |       | 3,rxd  |       |     |        |        |
// 10  | PC0    | DSEL0    |      |       | 1,TXD  |       |     |        |        |
// 11  | PC1    | DSEL1    |      |       | 1,RXD  |       |     |        |        |
// 12  | PC2    | RLYYEL   |      |       | 1,XCK  |       |     |        | 0,sda  |
//-----|--------|----------|------|-------|--------|-------|-----|--------|--------|
// 13  | PC3    | RLY1     |      |       | 1,XDIR |       |     |        | 0,scl  |
// 14  | VDDIO2 |          |      | 5V    |        |       |     |        |        |
// 15  | GND    |          |      | GND   |        |       |     |        |        |
// 16  | PC4    | RLY2     |      |       | 1,txd  |       |     |        |        |
// 17  | PC5    | RLY3     |      |       | 1,rxd  |       |     |        |        |
// 18  | PC6    | RLY4     |      |       | 1,xck  |       |     |        | 0,sda  |
// 19  | PC7    | RLYGRN   |      |       | 1,xdir |       |     |        | 0,sda  |
// 20  | PD0    | RIG1YEL  |      |       |        | AIN0  |     |        |        |
// 21  | PD1    | SPR1     |      |       |        | AIN1  |     |        |        |
// 22  | PD2    | KEY1\M   |      |       |        | AIN2  |     |        |        |
// 23  | PD3    | PTT1     |      |       |        | AIN3  |     |        |        |
// 24  | PD4    | RIG1GRN  |      |       |        | AIN4  |     |        |        |
//-----|--------|----------|------|--=----|--------|-------|-----|--------|--------|
// 25  | PD5    | RIG2YEL  |      |       |        | AIN5  |     |        |        |
// 26  | PD6    | SPR2     |      |       |        | AIN6  | OUT |        |        |
// 27  | PD7    | KEY2\M   |      |       |        | AIN7  |     |        |        |
// 28  | AVDD   |          |      | 5V    |        |       |     |        |        |
// 29  | AGND   |          |      | GND   |        |       |     |        |        |
// 30  | PE0    | PTT2     |      |       | 4,TXD  | AIN8  |     | 0,mosi |        |
// 31  | PE1    | IS       |      |       | 4,RXD  | AIN9  |     | 0,miso |        |
// 32  | PE2    | RIG2GRN  |      |       | 4,XCK  | AIN10 |     | 0,sck  |        |
// 33  | PE3    | RIG3YEL  |      |       | 4,XDIR | AIN11 |     | 0,ss\  |        |
// 34  | PF0    | SPR3     |      |       | 2,TXD  |       |     |        |        |
// 35  | PF1    | KEY3\M   |      |       | 2,RXD  |       |     |        |        |
// 36  | PF2    | PTT3     |      |       | 2,XCK  |       |     |        | 1,SDA  |
//-----|--------|----------|------|-------|--------|-------|-----|--------|--------|
// 37  | PF3    |          | PF3  |       | 2,XDIR |       |     |        | 1,SCL  |
// 38  | PF4    | RIG3GRN  |      |       | 2,txd  |       |     |        |        |
// 39  | PF5    | RIG4YEL  |      |       | 2,rxd  |       |     |        |        |
// 40  | PF6    | RESET    |      | RESET |        |       |     |        |        |
// 41  | UPDI   | UPDI     |      | UPDI  |        |       |     |        |        |
// 42  | VDD    | 5V       |      | 5V    |        |       |     |        |        |
// 43  | GND    | GND      |      | GND   |        |       |     |        |        |
// 44  | PA0    | TXD_M    |      |       | 0,TXD  |       |     |        |        |
// 45  | PA1    | RXD_M    |      |       | 0,RXD  |       |     |        |        |
// 46  | PA2    | SPR4     |      |       | 0,XCK  |       |     |        | 0,SDA  |
// 47  | PA3    | KEY4\M   |      |       | 0,XDIR |       |     |        | 0,SCL  |
// 48  | PA4    | PTT4     |      |       | 0,txd  |       |     |        |        |
//-----|--------|----------|------|-------|--------|-------|-----|--------|--------|
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

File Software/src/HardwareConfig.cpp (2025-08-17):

#include "HardwareConfig.h"
#include <Arduino.h>

void ConfigPins() {
  // USB interface configuratio
  pinMode(RTS1nPIN, INPUT);
  pinMode(RTS2nPIN, INPUT);
  pinMode(RTS3nPIN, INPUT);
  pinMode(RTS4nPIN, INPUT);

  pinMode(CTS2nPIN, OUTPUT);
  pinMode(CTS3nPIN, OUTPUT);
  pinMode(CTS4nPIN, OUTPUT);

  // RJ45 radio interface jack signals
  // KEY is low true, MCU internal pullup, protected with 3,6V zener
  pinMode(KEY1nPIN,  INPUT_PULLUP); 
  pinMode(KEY2nPIN,  INPUT_PULLUP); 
  pinMode(KEY3nPIN,  INPUT_PULLUP); 
  pinMode(KEY4nPIN,  INPUT_PULLUP); 

  pinMode(PTT1PIN,   OUTPUT);
  pinMode(PTT2PIN,   OUTPUT);
  pinMode(PTT3PIN,   OUTPUT);
  pinMode(PTT4PIN,   OUTPUT);

  // SPR is undefined, MCU internal pullup, no protection
  pinMode(SPR1PIN,   INPUT_PULLUP);
  pinMode(SPR2PIN,   INPUT_PULLUP);
  pinMode(SPR3PIN,   INPUT_PULLUP);
  pinMode(SPR4PIN,   INPUT_PULLUP);

  // RJ45 radio interface jack LEDs
  // LEDs are high true
  pinMode(RIG1GRNPIN, OUTPUT); // Rig Green, transmitting
  pinMode(RIG2GRNPIN, OUTPUT);
  pinMode(RIG3GRNPIN, OUTPUT);
  pinMode(RIG4GRNPIN, OUTPUT);
 
  pinMode(RIG1YELPIN, OUTPUT); // RIG Yellow, inhibited
  pinMode(RIG2YELPIN, OUTPUT);
  pinMode(RIG3YELPIN, OUTPUT);
  pinMode(RIG4YELPIN, OUTPUT);

  // RJ45 relay interface jack LEDs 
  pinMode(RLYGRNPIN,  OUTPUT); // Rig Green, something transmitting
  pinMode(RLYYELPIN,  OUTPUT); // RIG Yellow, something inhibited

  // RJ45 relay interface jack signals
  // RLY are high true, buffered with BTS5200 relay driver
  pinMode(RLY1PIN,   OUTPUT);
  pinMode(RLY2PIN,   OUTPUT);
  pinMode(RLY3PIN,   OUTPUT);
  pinMode(RLY4PIN,   OUTPUT);

  // BTS5200 relay driver
  pinMode(DSEL0PIN,  OUTPUT);
  pinMode(DSEL1PIN,  OUTPUT);
  pinMode(DENPIN,    OUTPUT);
  pinMode(ISPIN,     INPUT);
}

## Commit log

2025-07-03 initial commit of design for discussion
    [RF_Switch_4way.kicad_pcb, RF_Switch_4way.kicad_sch, SO4R_Interlock.kicad_pcb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]
2025-07-04 Moved 4:1 up a level
    [RF_Switch_4way.kicad_pcb, RF_Switch_4way.kicad_sch]
2025-07-11 Ordered V1 of Transfer Relay boards and Interlock boards and assembly
    [SO4R_Interlock-CuBottom.gbr, SO4R_Interlock-CuIn1.gbr, SO4R_Interlock-CuIn2.gbr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]
2025-07-13 started V2 of hardware board Started software development
    [SO4R_Interlock.kicad_pcb, SO4R_Interlock.kicad_sch]
2025-07-17 Hardware better names for PDF in documentation area started on V2 of hardware Connected reset\ to VDD on MCU added .lck to .gitignore Software improves reading RTS and KEY inputs all at one writing K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
    Relay signals derived from KEY and priority
    [SO4R_Interlock.kicad_pcb, SO4R_Interlock.kicad_sch]
2025-07-17 Updated README for clarity and current design
2025-07-23 reversed the RJ45 connectors
    [SO4R_Interlock.kicad_pcb, SO4R_Interlock.kicad_sch]
2025-08-04 replacing through holes with surface pads for RF to coax center pin wires
    [Transfer_G2RL.kicad_pcb, Transfer_G2RL.kicad_sch]
2025-08-17 Manually merged git branch V2 into main
    [IC-746PRO_cable.kicad_sch, IC-9100_cable.kicad_sch, K3S_cable.kicad_sch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]
2026-05-15 removed an obsolete board
2026-05-15 Remove obsolete Transfer_G2RL hardware project
    [Transfer_G2RL-CuBottom.gbr, Transfer_G2RL-CuTop.gbr, Transfer_G2RL-EdgeCuts.gbr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]

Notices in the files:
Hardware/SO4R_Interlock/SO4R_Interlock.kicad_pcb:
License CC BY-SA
